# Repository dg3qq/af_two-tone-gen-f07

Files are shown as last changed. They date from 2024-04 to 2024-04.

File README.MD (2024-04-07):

# AF-TWO-TONE-GENERATOR

##### cc-by-sa-nc DG3QQ rodi
##### rev. mar. 2024

# Bastel-Projekt zum 14. Giessener Amateurfunk Tag

+ [expose](F07-project/_expose.md]
+ video interview by Kirk (DO3KI) [14. Gießener Amateurfunktreffen 2024 - Doppeltongenerator Bauprojekt & ARRL Prüfung USA Rufzeichen](https://www.youtube.com/watch?v=AF0V_h3_ksM)

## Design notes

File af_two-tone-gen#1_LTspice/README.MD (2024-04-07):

# Two-Tone-Generator by DG3QQ 

#### copyright: dg3qq (cc-by-sa)

## Circuit Simulations

I used *LTSspice* to tweak parts of the circuit.

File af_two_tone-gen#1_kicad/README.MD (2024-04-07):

# Two-Tone-Generator by DG3QQ 

#### copyright: dg3qq (cc-by-sa)

## PCB in KiCad 

This was an attempt to port PCB development to KiCad. However, due to time constraints it was abandoned.

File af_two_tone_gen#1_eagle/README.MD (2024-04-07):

# Two-Tone-Generator by DG3QQ 

#### copyright: dg3qq (cc-by-sa-nc)

## PCB in EagleCad 

To get around delays, I resorted to a *free* version of EagleCad (6.xx).

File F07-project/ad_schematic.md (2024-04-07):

# Two Tone Generator (c) DG3QQ

##### Rev.: 17.Feb.2024

## Schaltplan - schematic 

SCH

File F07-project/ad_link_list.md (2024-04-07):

# Liks

##### Doc-Rev: 20240114-0023

## software 
+ [DL4YHF's Amateur Radio Software: Audio Spectrum Analyzer ("Spectrum Lab") ](https://www.qsl.net/dl4yhf/spectra1.html)

## websites

+ [DF1RN - NF-Zweitonmessungen am Elecraft KX3 [PDF]](https://www.darc.de/fileadmin/filemounts/distrikte/g/ortsverbaende/01/DF1RN/_16_-_17__NF-Zweitonmessungen_am_Elecraft_KX3_rev._1.1_df1rn_2018_06_25.pdf)
+ [box73 - Bauanleitung zum FA-2-NF-Zweitongenerator](https://www.box73.de/file_dl/bausaetze/BX-086.pdf)
+ [DC4KU - Messungen mit dem HF-Zweitongenerator FA-2-HF von FA [PDF]](https://dc4ku.darc.de/HF-Zweitongenerator_FA-2-HF.pdf)
+ [DC4KU HF-Zweitongenerator für IM3-Messungen an
SSB-Endstufen (PA's) und SSB-Empfängern [PDF]](https://dc4ku.darc.de/HF-Zweitongenerator.pdf)
+ []()
+ [DL2DAP_HF-Messpraxis und Messgeräte für Funkamateure 2021 [PDF]](https://forum.funk-telegramm.de/wcf/attachment/346-dl2dap-hf-messpraxis-und-messger%C3%A4te-f%C3%BCr-funkamateure-2021-pdf/)
+ [dk7ih - A simple 2-tone-generator for testing the linearity of SSB transmitters](https://dk7ih.de/a-simple-2-tone-generator-for-testing-the-linearity-of-ssb-transmitters/)
+ [PreciseRF - Application Note #2; Transmitter Two Tone Test [PDF]](https://preciserf.com/wp-content/uploads/2012/03/Appnote-2-Two-Tone-Tests2.pdf)
+ [Two-tone signal generator](https://www.robkalmeijer.nl/techniek/electronica/radiotechniek/hambladen/hr/1986/02/page25/index.html)

### circuit building block details:
+ [ee-diary: how does Twin-T oscillator work](https://www.ee-diary.com/2021/12/how-does-twin-t-oscillator-work.html#)
+ [Electronics Tutorials - Twin-T Oscillator](https://www.electronics-tutorials.ws/oscillator/twin-t-oscillator.html)
+ [elektroniktutor - sPassive elektrische Filterschaltungen](https://www.elektroniktutor.de/analogtechnik/filter.html#boucherot)

## video link collection

+ [Zweiton-Summensignal aus 700Hz und 1900Hz.]( https://www.youtube.com/watch?v=r9hPcu_xrlM)

+ [w2aew #7: Monitor your Ham Radio transmitter with an oscilloscope (en)](https://www.youtube.com/watch?v=y4Zt_LJX1Tc)
+ [w2aew #8: Two-tone test of SSB transmitter output (en)](https://www.youtube.com/watch?v=3DxBg6h4Fc8)
+ [w2aew #112: Use an Oscilloscope and Signal Generator help tune an HF Antenna, measure complex impedance (en)](https://www.youtube.com/watch?v=eYN7dhdt1Dw)
+ [w2aew #61: Basics of RF Samplers, Sampling-Tees, RF-taps, etc.(en)](https://www.youtube.com/watch?v=0Kk_N_TpDeo)
+ [MikesRadioRepair - Building a simple 2 tone audio generator for testing SSB radios.](https://www.youtube.com/watch?v=bIG2McK9QRQ)

+ [Icom IC-7300 Tips and Tricks - Using Two Tones to Check Linearity](https://www.youtube.com/watch?v=NapPt2sxBVE)
+ []()
+ []()
+ [Kurzwellen SSB Funkgerät nachbauen Teil 1](https://www.youtube.com/watch?v=Qace0_og6LY)
+ [Kurzwellen SSB Funkgerät nachbauen Teil 2](https://www.youtube.com/watch?v=GwzsfukFg70)
+ [Kurzwellen SSB Funkgerät nachbauen Teil 3 es funktioniert](https://www.youtube.com/watch?v=KoNCUYpN4dw)
+ [1 Watt Kurzwellen SSB Funkgerät Schaltplan Teil 4](https://www.youtube.com/watch?v=3-fIp6_WNEs)
+ [https://www.youtube.com/watch?v=M98ClS4ekHA](https://www.youtube.com/watch?v=M98ClS4ekHA)

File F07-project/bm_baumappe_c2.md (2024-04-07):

# Zwei-Ton-Generator - DARC F07 Project (c) DG3QQ

#####  Doc-Rev: 20240224-1440

# Baumappe - Kaptel 2

## Bestückung-Anleitung des PCB

Nachfolgend werden detailliert die Schritte der Bestückung der Platine beschrieben.

Bitte folgen Sie der gegebenen Reihenfolge, denn diese haben sich als sinnvoll und praktikabel erwiesen.

### Bestand-Aufnahme
Bevor es an's Bestücken geht, hat es sich immer als sinnvoll erwiesen, die Vollständigkeit der Materialien zu prüfen.

Bitte identifizieren und prüfen Sie anhand der [Stückliste](ad_bom_sum.md) die Bauteile. Und stellen Sie sicher, dass alle vorhanden sind.

Sortieren sie die dabei die Widerstände. Unter Umständen sind einige der Farbringe nur schwer zu identifizieren; wenn nötig benutzen sie ein Vergrößerungsglas. Am besten benutzen sie ein Multimeter 
um die Werte zu überprüfen.

### Poti's, Schalter und LED zuerst
Die Poti's, Schalter und LED sollen von außen bedienbar bzw. sichtbar sein! 

Deshalb platzieren Sie die Poti's (VR1..VR3), Schalter (S1, S2) und die LED (LED1). Aber noch nicht einlöten! 

Bei der LED ist auf die Polarität zu achten. 

LED polarity advice

Richten Sie diese Bauelemente entsprechen aus und 'heften' (tack solder) Sie diese in Position. 

Wenn alles passt, können Sie die Poti's, Schalter und LED zuverlässig verlöten.

>!Note Leider konnten die im Labormuster verwendeten Sub-Miniatur-Schalter weder in dieser noch vergleichbaren Bauform (zum Termin) beschafft werden. Statt dessen werde funktionsgleiche aber etwas größere mit Litze-Drähten mit dem PCB verbunden.

### Und jetzt fertig bauen

Wer die Funktion der Schaltung verstanden hat, oder ein erfahrener *Nachbauer* ist, mag gerne die folgenden Anweisungen zur weiteren Bestückung der Platine überspringen und *In eigen Regie* weiter bauen. (Nict empfohlen) [->weiter zu Kapitel PCB_Fertig](#PCB_Fertig)

### Schritt für Schritt Anweisungen

Nachdem Sie jetzt VR1.. S1.. und LED1 platziert haben, 
fahren wir mit den den weiteren, Bauteilen fort:

#### Bestückung - Stromversorgung
Die LED1 wurde schon im vorhergehenden Schritt bestückt. Um den Stromversorgung-Teil zu vervollständigen, bestücken sie nun noch:

+ [_] R1 Widerstand 560R 0,25W stehend (grün-blau-braun). 
> !NOTE: Setzen Sie diesen, abweichend vom Bestückungsdruck in umgekehrter Weise ein. Dann kann am langen Ende zu Testzwecken per Laborklemme die Schaltung provisorisch mit *PLUS* der Batterie-Versorgung verbunden werden.

+ [_] C1 Kondensator 100nF (104)

##### Test - Stromversorgung
Jetzt kann ein erster Test dieses Schaltungsteil erfolgen.

Verbinden Sie vorübergehend die Batterie (oder eine vergleichbare Spannungsquelle) mit dem PCB. 

Durch betätigen der Schalter sollte sich folgendes ergeben:

| Schalter | LED | 
| :--- | :--- |
| beide aus | dunkel |
| mindestens einer oder beiden ein | leuchtet |

Wenn die LED in keiner der Stellungen leuchtet, prüfen Sie deren Polarität/Einbau.

#### Bestückung - Erster Oszillator

Bestücken Sie:

+ [_] Widerstand R2 47k liegend (gelb-vio-orange)
+ [_] Widerstand R4 47k stehend (gelb-vio-orange)
+ [_] Kondensator C4 10nF (103)
+ [_] Kondensator C4B 3,3nF (332)
+ [_] Kondensator C3 10nF (103)
+ [_] Kondensator C3B 3,3nF (332)
+ [_] Kondensator C2 22nF (223)
+ [_] Kondensator C5 1µF (105)
+ [_] Kondensator C6 22nF (223)
+ [_] Kondensator C7 22nF (223)
+ [_] Testpunkt TF1 (1x2 pinstrip Sockel (RM2.5))
+ [_] Widerstand R6 4k7 stehend (gelb-vio-rot)
+ [_] Widerstand R7 4k7 stehend (gelb-vio-rot)
+ [_] Transistor T1 NPN-Transistor 2N3904 (o.ä.) 
> Eventuell müssen die Beinchen etwas gebogen werden, damit sie gut in die Bohrungen passen.

#### Bestückung - Zweiter Oszillator

Bestücken Sie:

+ [_] Widerstand R9 33k liegend (orange-orang-orange)
+ [_] Widerstand R10 33k stehend (orange-orang-orange)
+ [_] Widerstand R11 2k2 stehend (rot-rot-braun)
+ [_] Kondensator C9 4,7nF (472)
+ [_] Kondensator C10 4,7nF (472)
+ [_] Kondensator C8 10nF (103)
+ [_] Kondensator C11 1µF (105)
+ [_] Kondensator C12 3,3nF (332)
+ [_] Kondensator C13 3,3nF (332)
+ [_] Testpunkt TF2 (1x2 pinstrip Sockel (RM2.5))
+ [_] Widerstand R12 10k stehend (braun-schwarz-orange)
+ [_] Widerstand R13 10k stehend (braun-schwarz-orange)
+ [_] Transistor T2 NPN-Transistor 2N3904 (o.ä.) (Beinchen biegen)
+ [_] Testpunkt SG (1x2 pinstrip Sockel (RM2.5))

####Bestückung - Ausgang-Puffer-Stufe

Bestücken Sie:

+ [_] Widerstand R20 10k stehend (braun-schwarz-orange)
+ [_] Widerstand R21 10k stehend (braun-schwarz-orange)
+ [_] Widerstand R22 560R stehend (grün-gelb-braun)
+ [_] Widerstand R26 27k stehend (rot-vio-orange)
+ [_] Widerstand R24 5k6 stehend (grün-gelb-rot)
+ [_] Widerstand R25 560R stehend (grün-gelb-braun)
+ [_] Widerstand R23 560R stehend (grün-gelb-braun)
+ [_] Testpunkt  SIG_ (1x3 pinstrip Sockel (RM2.5))
+ [_] Kondensator/Elko C15 10µF radial (Polarität beachten)
+ [_] Kondensator/Elko C16 220µF radial (Polarität beachten)
+ [_] Transistor T3 NPN-Transistor 2N3904 (o.ä.) (Beinchen biegen) 

## PCB Fertig

Sie haben die Platine fertig bestückt. Zum Abschluss nun noch den Batteriehalter verbinden und drei Batterien (Typ-AAA) einlegen.

Nun kann getestet und eingestellt werden.

Am besten prüfen Sie die Funktion mit einem Oszilloskop.

+ [_] Stellen Sie mit VR1 die Frequenz des Oszillator (um T1) auf typisch 700Hz ein.
+ [_] Stellen Sie mit VR2 die Frequenz des Oszillator (um T2) auf typisch 1900Hz ein.
+ [_] Regeln Sie mit VR3 die *Balance* der beiden Signale so, dass sie im Gemisch gleiche Amplitude haben.
Siehe [Benutzer-Anleitung](om_benutzer_anleitung.md) 

### analog oszi schirmbild

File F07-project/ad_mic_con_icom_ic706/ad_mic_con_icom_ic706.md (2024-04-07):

# Zwei-Ton-Generator - DARC F07 Project (c) DG3QQ

#####  Doc-Rev: 20240219-2120

#  Baumappe - Anhang

## Mikrofon-Anschluß f. ICOM IC-706 u.ä.

## 
| PIN  | Signal | Farbe |
| :---: | --- | --- |
| 1 | +8V !!max. 10mA | rot |
| 2 | UP/DOWN | blau  |
| 3 | AUDIO OUT | n/a |
| 4 | PTT | gelb  |
| 5 | MIC GROUND | grau  |
| 6 | MIC | weiss |
| 7 | GROUND/EARTH | grün  |
| 8 | SQUELCH | braun |
  
>note +8V nicht strombegrenzt - Bei Überstrom TRX kaput !
 
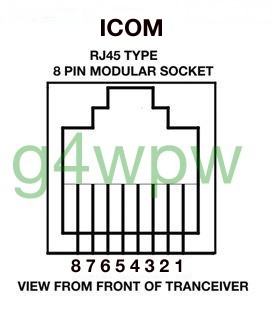
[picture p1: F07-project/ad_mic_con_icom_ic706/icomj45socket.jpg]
icom RJ45

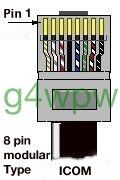
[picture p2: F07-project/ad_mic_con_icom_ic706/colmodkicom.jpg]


### ICOM HM103
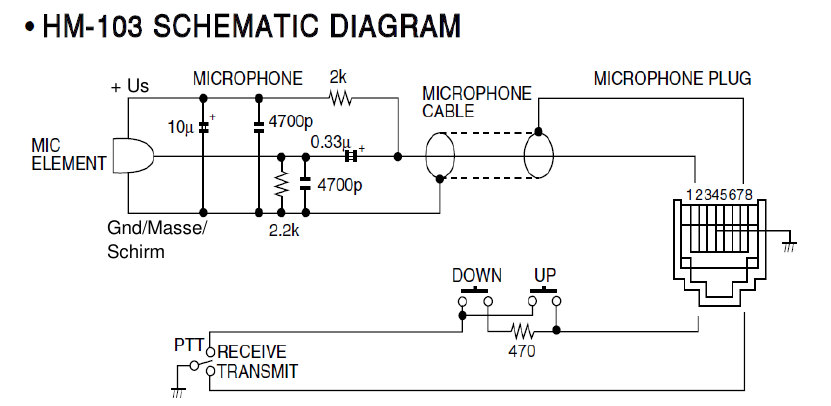
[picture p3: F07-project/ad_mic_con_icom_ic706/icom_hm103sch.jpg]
icom HM103


[g4wpw](https://www.qsl.net/g4wpw/date.html)

![]()

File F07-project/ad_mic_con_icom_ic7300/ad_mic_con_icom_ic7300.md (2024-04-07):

# Zwei-Ton-Generator - DARC F07 Project (c) DG3QQ

#####  Doc-Rev: 20240219-2300

#  Baumappe - Anhang

## Mikrofon-Anschluß f. ICOM IC-7300 

## 
| PIN | Signal | Farbe |
| :---: | --- | --- |
| 1 | MIC | |
| 2 | +8V | |
| 3 | MIC_U/D | |
| 4 | SQL | |
| 5 | PTT | |
| 6 | GND | |
| 7 | MICE | |
| 8 | AF_OUT | |
  
>note +8V 10mA max.
 
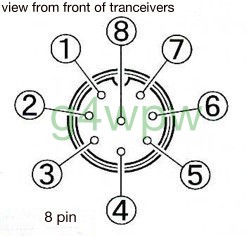
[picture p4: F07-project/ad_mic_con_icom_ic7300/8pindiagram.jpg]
icom 8pin
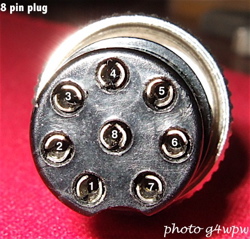
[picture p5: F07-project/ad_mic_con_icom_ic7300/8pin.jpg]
 
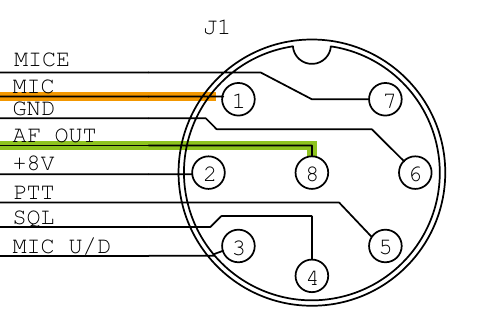
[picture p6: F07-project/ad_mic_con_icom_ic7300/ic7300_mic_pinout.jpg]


### ICOM HM-219
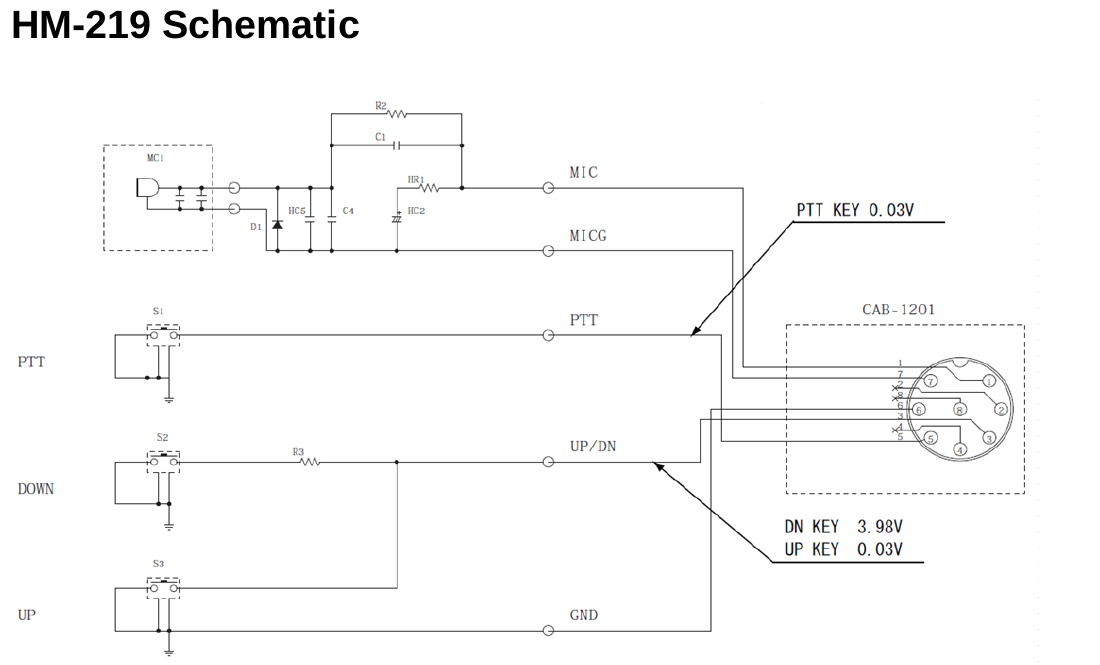
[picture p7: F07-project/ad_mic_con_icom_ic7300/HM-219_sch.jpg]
icom HM-219 schematic


[g4wpw](https://www.qsl.net/g4wpw/date.html)

![]()

## microphon input specs

impedance: 600Ohm
pegel: (von service manual addendum; 4-4 TX POWER ADJUSTMENTS) Level : 30 mVrms

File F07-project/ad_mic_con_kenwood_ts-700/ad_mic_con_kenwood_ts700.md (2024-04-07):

# Zwei-Ton-Generator - DARC F07 Project (c) DG3QQ

#####  Doc-Rev: 20240219-2120

#  Baumappe - Anhang

## Mikrofon-Anschluß f. KENWOOD TS-700G u.ä.

## 
| PIN  | Signal |
| :---: | --- |
| 1 | MIC |
| 2 | PTT |
| 3 | PTT GND |
| 4 | MIC GND |
    
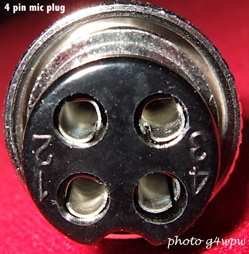
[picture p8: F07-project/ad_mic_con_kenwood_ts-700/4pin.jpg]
4pin
    

### kenwood MC-10
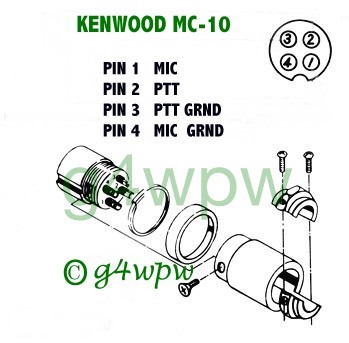
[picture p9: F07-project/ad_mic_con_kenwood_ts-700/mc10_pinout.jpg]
kenwood


[g4wpw](https://www.qsl.net/g4wpw/date.html)

![]()

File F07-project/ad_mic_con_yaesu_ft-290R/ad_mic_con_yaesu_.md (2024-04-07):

# Zwei-Ton-Generator - DARC F07 Project (c) DG3QQ

#####  Doc-Rev: 20240219-2120

#  Baumappe - Anhang

## Mikrofon-Anschluß f. YAESU FT-290R u.ä.

## 
| PIN  | Signal |
| :---: | --- |
| 1 | MIC Schirm/Masse |
| 2 | MIC |
| 3 | PTT |
| 4 | + 12VOLT ( + 5 VOLTS FT730-FT290R ) |
| 5 | SPEAKER |
| 6 | UP |
| 7 | DOWN |
    
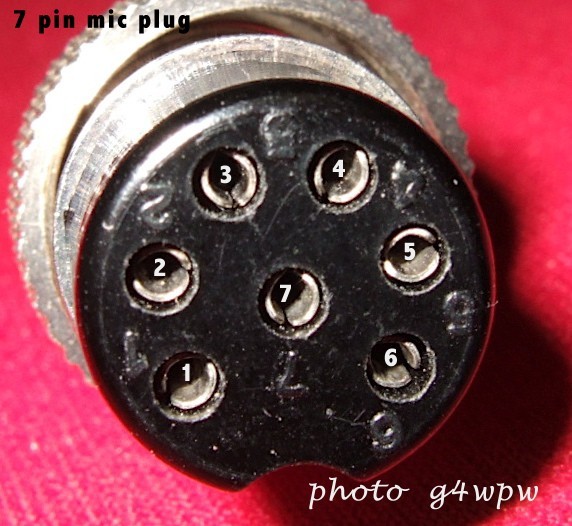
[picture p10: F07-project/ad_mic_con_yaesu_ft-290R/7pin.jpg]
7pin
    

### yaesu YM-47
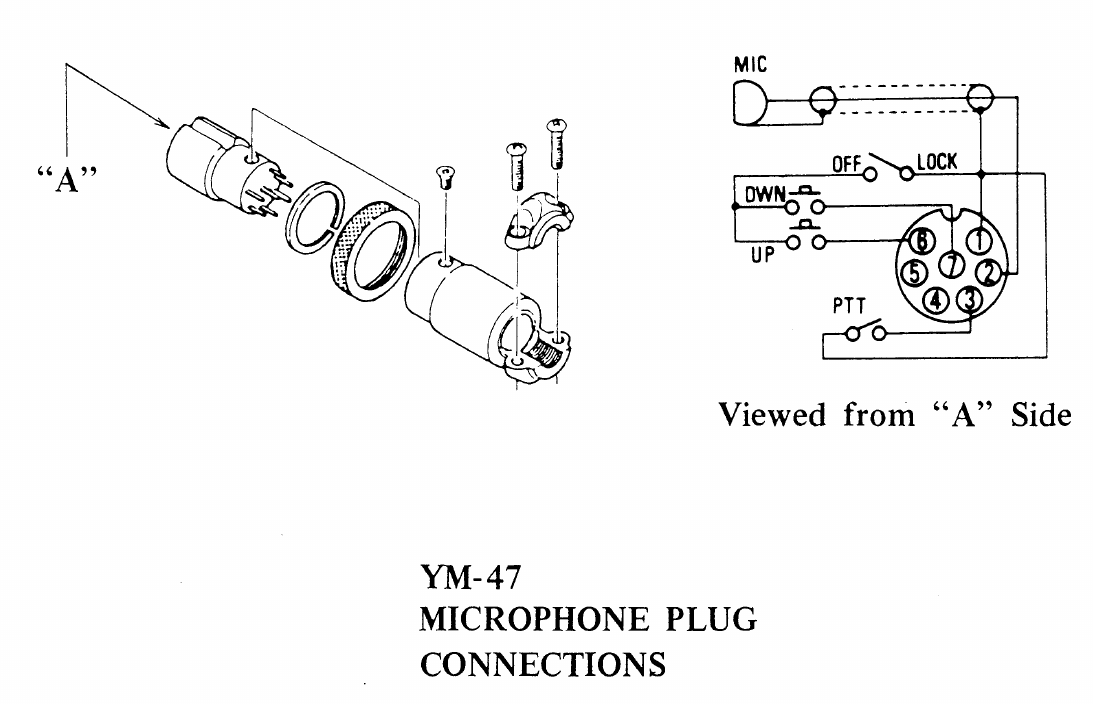
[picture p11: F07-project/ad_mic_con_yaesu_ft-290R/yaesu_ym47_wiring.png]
yaesu YM-47


### yaesu YM-49
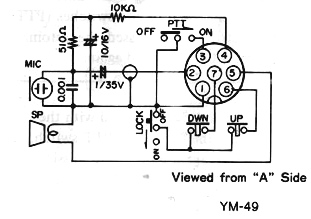
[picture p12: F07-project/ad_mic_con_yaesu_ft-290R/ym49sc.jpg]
yaesu YM-49


[g4wpw](https://www.qsl.net/g4wpw/date.html)

![]()

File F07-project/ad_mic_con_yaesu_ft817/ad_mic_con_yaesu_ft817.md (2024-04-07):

# Zwei-Ton-Generator - DARC F07 Project (c) DG3QQ

#####  Doc-Rev: 20240219-2120

#  Baumappe - Anhang

## Mikrofon-Anschluß f. YAESU FT-817 u.ä.

## 
| PIN | Signal | Farbe |
| :---: | --- | --- |
| 1 | FAST SCAN.  | rot (red) |
| 2 | GROUND. | braun (brown) |
| 3 | PTT. | gelb (yellow) |
| 4 | MIC. | weiss (white) |
| 5 | MIC GROUND. | schwarz (black) |
| 6 | + 5 VOLTS.  | grün (green) |
| 7 | UP. | blau (blue) |
| 8 | DOWN. | schwarz (black) | 

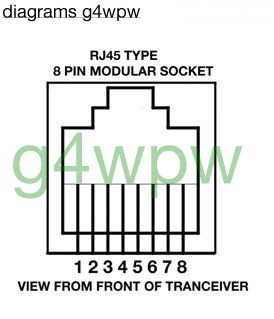
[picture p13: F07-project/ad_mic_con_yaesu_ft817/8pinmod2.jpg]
RJ45
    

### yaesu HM-31A8J
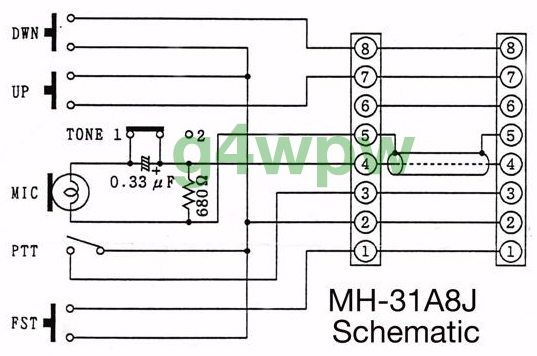
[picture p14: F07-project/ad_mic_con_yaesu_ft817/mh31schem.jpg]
MH31 schematic


### yaesu MH-31 Specifications
+ Microphone Element: Dynamic
+ Audio Tone Response: Tone 1 Full range. Tone 2 -14dB ±3 dB at 100 Hz
+ Sensitivity: -78 dB ±3dB at 1 kHz
+ Microphone Impedance: 190 Ohms ±30% at 1 kHz (Tone 1)
+ Dimensions: 2.5 x 4.5 x 1.25 inches
+ Weight: 7 ounces (183 g). 

[g4wpw](https://www.qsl.net/g4wpw/date.html)

## yaesu 6-pin mini-DIN (FT-817)
| PIN  | Signal |
| :---: | --- |
| 1 | Data In (1Vpp; 10kOhm)|
| 2 | GROUND |
| 3 | PTT |
| 4 | Data Out 9600bps |
| 5 | Data Out 1200bps (300mVpp; 10kOm)|
| 6 | SQL |

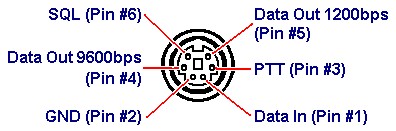
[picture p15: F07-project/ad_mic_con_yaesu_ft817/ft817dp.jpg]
DATA port
6-pin mini-DIN (FT-817) DATA port

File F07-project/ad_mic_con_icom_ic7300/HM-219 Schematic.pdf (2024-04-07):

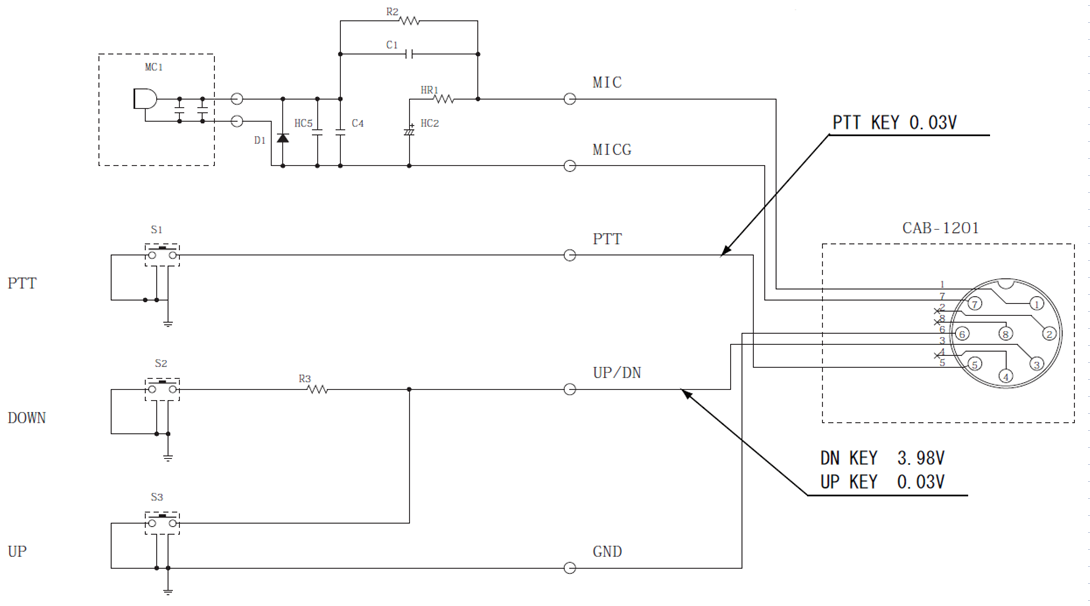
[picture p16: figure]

1

# Knowledge Base |

©2018 Icom America Inc. The Icom logo is a registered trademark of Icom Inc.

# HM-219 Schematic

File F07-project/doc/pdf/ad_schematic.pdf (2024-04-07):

Two Tone Generator (c) DG3QQ

Rev.: 17.Feb.2024
Schaltplan - schematic

1

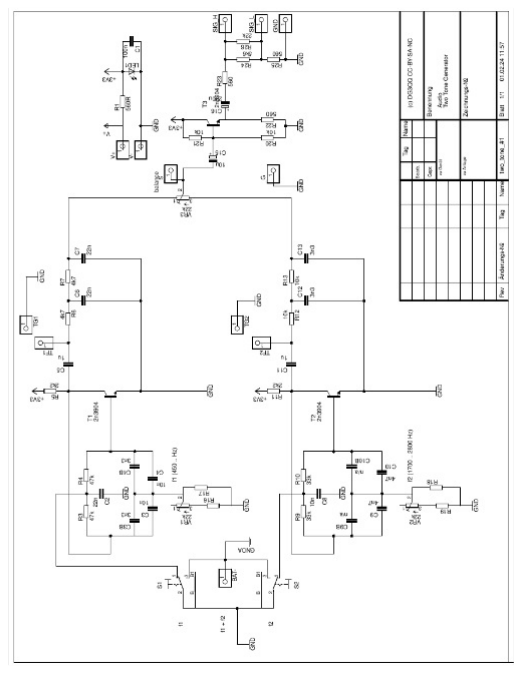
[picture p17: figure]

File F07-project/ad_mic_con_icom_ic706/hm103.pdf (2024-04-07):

# HM 103 Handmikrofon

# funktioniert auch am IC-7000

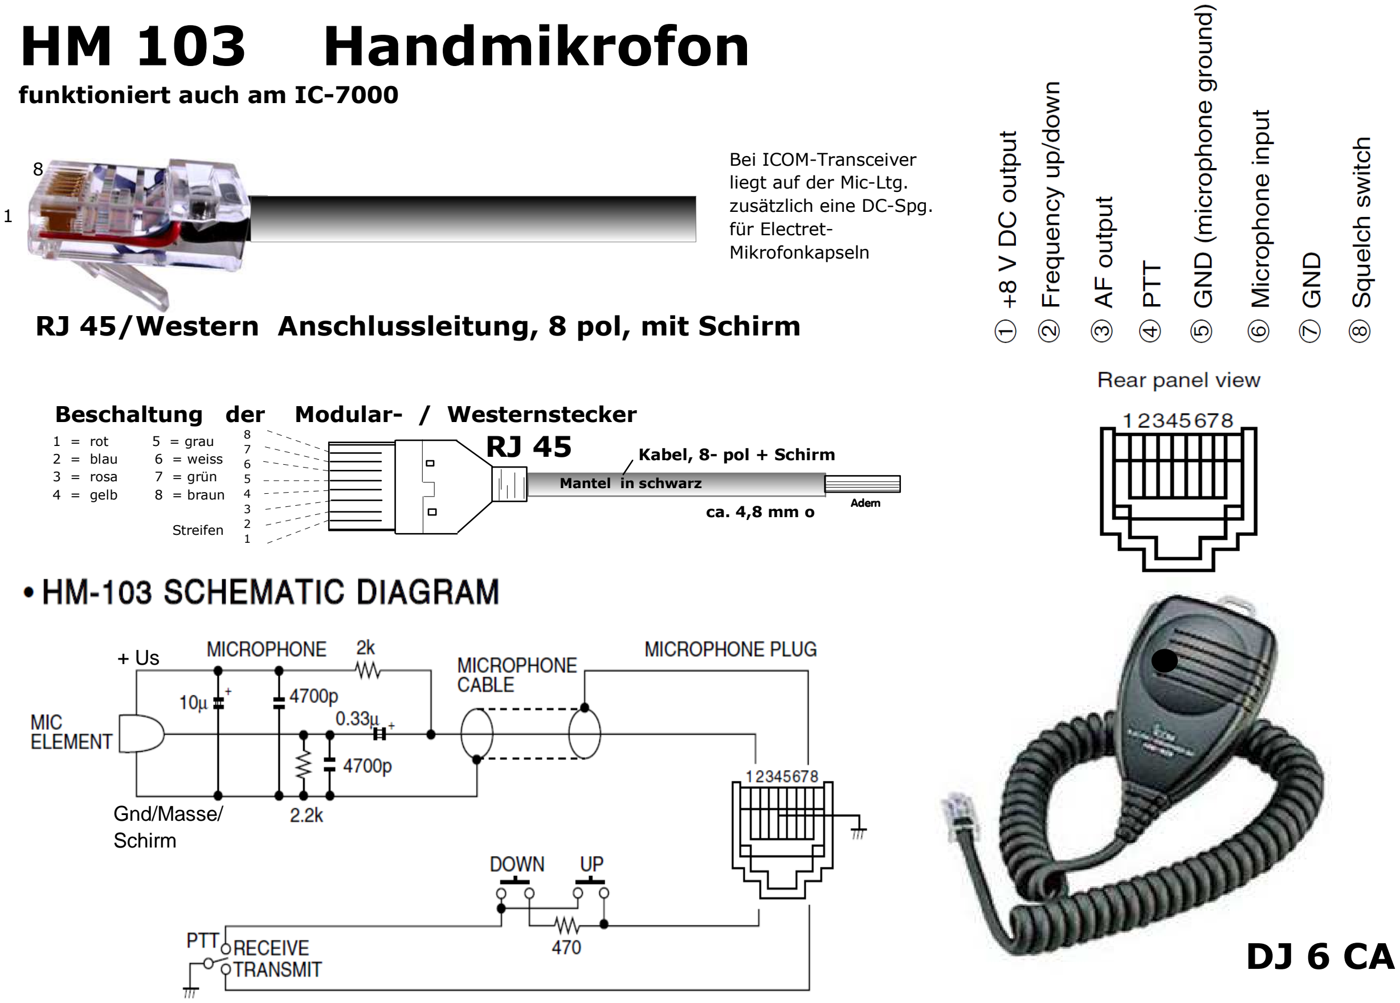
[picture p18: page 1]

# RJ 45/Western Anschlussleitung, 8 pol, mit Schirm

8

1

## Beschaltung der Modular- / Westernstecker

### Kabel, 8- pol + Schirm

Adern

Mantel in schwarz

ca. 4,8 mm o

RJ 45 ¹ = rot | 5 = grau 2 = blau | 6 = weiss
3 = rosa | 7 = grün
4 = gelb | 8 = braun

Streifen

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
# DJ 6 CA

+ Us

# Gnd/Masse/ Schirm

### Bei ICOM-Transceiver

liegt auf der Mic-Ltg.
zusätzlich eine DC-Spg.

### für Electret-Mikrofonkapseln

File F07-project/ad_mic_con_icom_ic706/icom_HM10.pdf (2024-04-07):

## IC-HM10

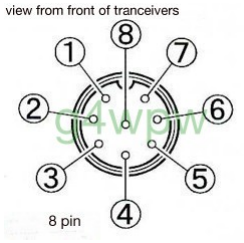
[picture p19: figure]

PIN 1 | MIC.
PIN 2 | +9 volt.
PIN 3 | UP/DOWN.
PIN 4 | SQUELCH.
PIN 5 | PTT.
PIN 6 | PTT GROUND.
PIN 7 | MIC GROUND.
PIN 8 | N/C.
HM10 | https://www.qsl.net/g4wpw/hm10.html
1 von 1 | 15.02.24, 21:47

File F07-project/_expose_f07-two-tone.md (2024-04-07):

# *TWO TONE TEST OSZILLATOR*  - ein Selbstbau-Projekt
##### Exposee; Rev.: 27.Dec.2023

##### ToDo: 
[ ] Rechtschreibprüfung

Noch eines; warum nicht? - Es stand die Frage im Raum, ob der OV-F07 für 2024 ein "Bastel-Projekt" realisiert.

## Anforderungen zur Entwicklung:
 + soll in eine *"Pfefferminz Dose"* passen. Oder zumindest nicht viel größer sein.
 + Batterie betrieben (3x AAA)
 + keine SMD sondern nur bedrahtete Bauteile (THT); eben was zum anfassen ;) !
 + keine µController

## Schaltung-Beschreibung
Der Hauptteil des Geräts besteht aus zwei Twin-T-Oszillatoren (Transistorschaltung). 
Deren Frequenz kann jeweils mittels eines Spindel-Trimers eingestellt werden. 
Die beiden Signale werden danach über einen weiteren Spindel-Trimer, zur *Balance*-Einstellung, gemischt. 
Eine nachfolgende Verstärkerstufe dient der Entkopplung und Impedanzanpassung.

Für den Aufbau der Schaltung auf der Leiterplatte kommen bedrahtete Bauteile zum Einsatz.

Die Anfertigung von Anschlusskabel(n) für das zu testende Geräte, ist wegen der Vielfalt, dem Besitzer/Erbauer überlassen. 
Jedoch werden in der Baumappe Beispiele hierfür gegeben. 

## Bauteile:
 + 3 Transistoren, 1 3mm ø LED
 + 3 Spindeltrimmpoti
 + 2 Miniatur-Kippschalter
 + 22 Widerstände (1/4W)
 + 17 Kondensatoren
 + 2 Al-Elko

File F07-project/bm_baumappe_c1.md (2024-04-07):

# Zwei-Ton-Generator - DARC F07 Project (c) DG3QQ

#####  Doc-Rev: 20240205-1257

#  Baumappe - Kapitel 1

## Schaltungsbeschreibung

### Überblick / Blockdiagramm
block diagram

Wie im obigen Blockdiagramm dargestellt, besteht der beschriebene Zweiton-Generator aus zwei Oszillatoren mit jeweils einem nachgeschalteten Tiefpass. Die Frequenzen sind mit RV1 bzw. RV2 in gewissem Maße einstellbar. 

Danach werden die beiden NF-Sinus-Signale in einer passiven Mischstufe (RV3) einander überlagert.

Abschließend folgt eine Impedanzwandler-/Puffer-Stufe (T3). In deren Auskopplung ist auch ein Abschwächer vorhanden.

Nachfolgend werden die einzelnen Stufen näher beschrieben. 

#### Oszillator-Schaltung

Als Oszillator-Schaltung kommt hier die "Twin-T"-Konfiguration mit einem NPN-Transistor als Verstärker zum Einsatz.

Andere Oszillator-Schaltungen, wie z.B. Wien-Brücke, Phasen-Netzwerk o. andere, erfordern mehr Aufwand an Bauteilen/Schaltung-Komplexität. Oder sind nicht geeignet mit einfachen Mitteln, innerhalb eine Oktave nach oben oder unten verstimmt/eingestellt zu werden. 

Twin_T_oscillator

[wikipedia: Twin-T_oscillator](https://en.wikipedia.org/wiki/RC_oscillator#Twin-T_oscillator)

Der Oszillator besteht aus einem Verstärker und einem Rückkopplung-Netzwerk. 

In diesem speziellen Fall ist es eine Parallelschaltung von RCR-Tiefpass und CRC-Hochpass in T-Anordnung

Mit :
R1 = R; R2 = 1/2 * R und

C1 = C; C2 = 2 * C

Gilt für die Bestimmung der Frequenz:

"fc={\frac {1}{2\pi RC}}"

Durch Variation von Widerstand (R2) ist es, in begrenztem Maße möglich, die Resonanzfrequenz zu ziehen; Plus/Minus eine halbe Oktave geht.

Viel tiefer in die Funktionsweise der "Twin-T"-Oszillatorschaltung möchte ich hier aber nicht weiter eingehen. -> [elektronik-labor. de - Eintransistor-Sinusoszillator (www.elektronik-labor.de/Notizen/SinusOsz.html)](https://www.elektronik-labor.de/Notizen/SinusOsz.html)

Halbleiter-Schaltungstechnik, Tietze, Ulrich; Schenk, Christoph; Springer-Verlag  

#### Tiefpass-Filter

Eine "Twin-T"-Oszillatorschaltung ist gegenüber einem *Wien*-Oszillator mit einem höheren Klirrfaktor behaftet. Dem wird hier mit passiven (RC)-Tiefpass-Filtern in ausreichender weise entgegen gewirkt.

#### NF-Überlagerung / Mischer u. Balance Einstellung

Die Überschrift für diese Stufe erscheint komplizierter als es ist.

Die NF-Signale der vorausgehenden Stufen werden an die gegenüberliegenden Enden  eines Potentiometer eingespeist. An dessen Abgriff bildet sich dann das Überlagerung-Signal.

Je nach Eingang-Amplitude und Stellung des Abgriff wird hier (mit VR3) die *Balance*
der beiden Tonsignale im Verhältnis 1:1 eingestellt.

#### Puffer-/Impedanzwandler-Stufe

Eigentlich könnte man hier aufhören und das Signal an dieser Stelle ausleiten. 

Es ist jedoch sinnvoll hier eine  niederohmige Impedanz-/Puffer-Stufe (T3) vorzusehen. 

#### Spannungsversorgung

Da das Gerät für den ungebundene Einsatz konzipiert wurde, sind zur Versorgung Primär-Zellen (3xAAA) vorgesehen.

Die Spannung-Stabilisierung erfolgt durch eine "Shunt"-Schaltung. Eine LED (blau; ø3mm) wird als Referenz eingesetzt. Zusätzlich dient diese LED auch als Betrieb-Anzeige.

#### Funktionskontrolle

Bezüglich der Funktion-Kontrolle muss hier besonders auf die Verwendung der Kontakte der beiden Schalter hingewiesen werden.

Zum einen verbinden diese jeweils den Negativ-Batterie-Anschluss mit der Schaltung (ODER Verknüpfung).

Zum anderen kann der Kondensator im Tiefpasszweig am "Twin-T"-Oszillator gegen Masse gebrückt werden (aus). 

Auf diese weise wird möglich mit nur zwei einpoligen Umschaltern (SPST) folgendes Funktion-Verhalten zu erreichen.
 
| S1 | S2  | Stromversorgung | Ausgang (Frequenz) |
| --- | --- | :--- | --- |
| aus | aus | aus; Batterie nicht verbunden | 0 |
| ein  | ein  | ein; Batterie verbunden | f1 + F2 | 
| ein  | aus | ein; anderer Oszillator (f2) gesperrt | f1 | 
| aus | ein  | ein; anderer Oszillator (f1) gesperrt | f2 |

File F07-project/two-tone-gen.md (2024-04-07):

# Project Audio Two Tone Generator (C) DG3QQ  

##### Doc-Rev: 20240114-0023
#### copyright: dg3qq (cc-by-sa)

## Dokumente in deutscher Sprache
- [Expose f07-two-tone-expose.md](f07-two-tone-expose.md)
- [Baumappe bm_baumappe.md](bm_baumappe.md)
- [Benutzer Anleitung om_benutzer_anleitung.md](om_benutzer_anleitung.md)
- [DUT Adapter Beispiele ad_dut_harness_de.md](ad_dut_harness_de.md)

## Documents in english
- [Builder's manual bm_build_manual.md](bm_build_manual.md)
- [Operation manual om_operator_manual.m](om_operator_manual.md)

## Apendix / Anhang
- [Bill Of Materials - Stückliste ad_bom.md](ad_bom.md)
- [Schematic - Schaltplan ad_schematic.md](ad_schematic.md)

## links other
Wenn man im Internet sucht, wird man viele Artikel zu diesem Thema finden.

+ [wikipedia:Zweiton.jpg; Cqdx; CC BY-SA 3.0 Deed](https://de.wikipedia.org/wiki/Datei:Zweiton.jpg)
+ [Cqdx; CC BY-SA 3.0 Deed](https://de.wikipedia.org/wiki/Datei:Zweiton.jpg)

+ [wikipedia - Zweitonanregung](https://de.wikipedia.org/wiki/Zweitonanregung) 
+ [wikipedia - Two-tone testing](https://en.wikipedia.org/wiki/Two-tone_testing)
+ [dc4ku - NF-Doppeltongenerator für IM3-Messungen an SSB-Sender](https://dc4ku.darc.de/NF-Doppelton-Generator.pdf)
+ [dc4ku - Intermodulationsmessung_an_HF-Sendern und HF-Endstufen (PA)](https://dc4ku.darc.de/Intermodulationsmessung_an_HF-Sendern.pdf)

+ [dl6gl - Klirrarmer Zweitongenerator; dl6gl](https://dl6gl.de/klirrarmer-zweitongenerator.html)
+ [aarl - Test Procedures Manual](https://www.arrl.org/files/file/Technology/Procedure%20Manual%202011%20with%20page%20breaks.pdf) Two-Tone Audio
Generator pp. 140
+ [cwtd - Analyze This! ... Two-Tone Test Oscillator](http://www.cwtd.org/Sep17.html)
+ [vk6ysf - SINGLE SIDE BAND TWO TONE TEST](https://vk6ysf.com/ssb_2tone_test.htm)
+ [dk7ih - A simple 2-tone-generator for testing the linearity of SSB transmitters](https://dk7ih.de/a-simple-2-tone-generator-for-testing-the-linearity-of-ssb-transmitters/)
+ [oz1bxm - Designing and Building a Two-Tone Generator](http://oz1bxm.blogspot.com/2016/04/designing-and-building-two-tone.html)
+ [ELECRAFT - 2T-gen 2-Tone TESTOSCILLATOR](https://ftp.elecraft.com/Mini%20Modules/Manuals%20Downloads/2T-Gen_Manual_Rev_B.pdf)
+ [pc2c - Two tone LF generator](https://www.pc2c.nl/two_tone_gen.php)
+ [kx4om - Two-Tone Generator](https://www.qsl.net/kx4om/Projects/Two-ToneGen/Two-Tone_Generator.html)
+ [DK7IH - Das QRP-Baubuch – Kapitel 4 (Teil 5) 4.11.1 Das Zweitonverfahren](https://dk7ih.de/das-qrp-baubuch-kapitel-4-5/)
+ []()
+ []()
+ []()

+ [VU2ESE - Two Tone HF-Generator](https://www.vu2ese.com/index.php/2020/06/19/two-tone-generator/)

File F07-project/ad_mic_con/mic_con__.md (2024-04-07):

# Zwei-Ton-Generator - DARC F07 Project (c) DG3QQ

#####  Doc-Rev: 20240219-2120

#  Baumappe - Anhang

## Mikrofon-Anschluß - allgemeine Hinweise

+ Eingangsschaltung des DUT
+ Bei DUT (Elektret-Mikrofon) Koppelkondensator in Mikrofon-Leitung (4,7µF)
+ Pegel:
    + Dyn-Mikrofon = ca. 2mV (ohne ext. Vorverstärker)
    + Elektret = 20 mV bis 100mV
    
## 
| PIN  | Signal |
| :---: | --- |
| 1 |  |
| 2 |  |
| 3 |  |
| 4 |  |
| 5 |  |
| 6 |  |
| 7 |  |
    
7pin    

### ?? 
??

[g4wpw](https://www.qsl.net/g4wpw/date.html)

![]()

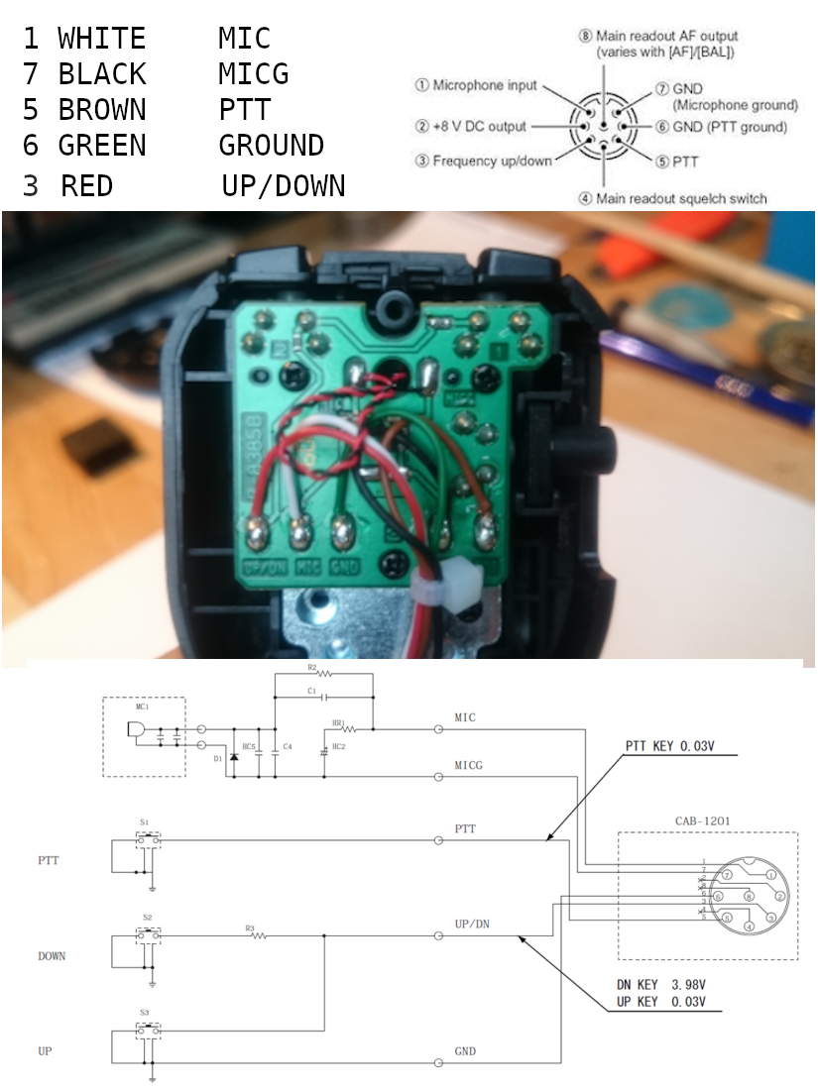
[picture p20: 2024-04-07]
F07-project/ad_mic_con_icom_ic7300/HM-219-schematic.png

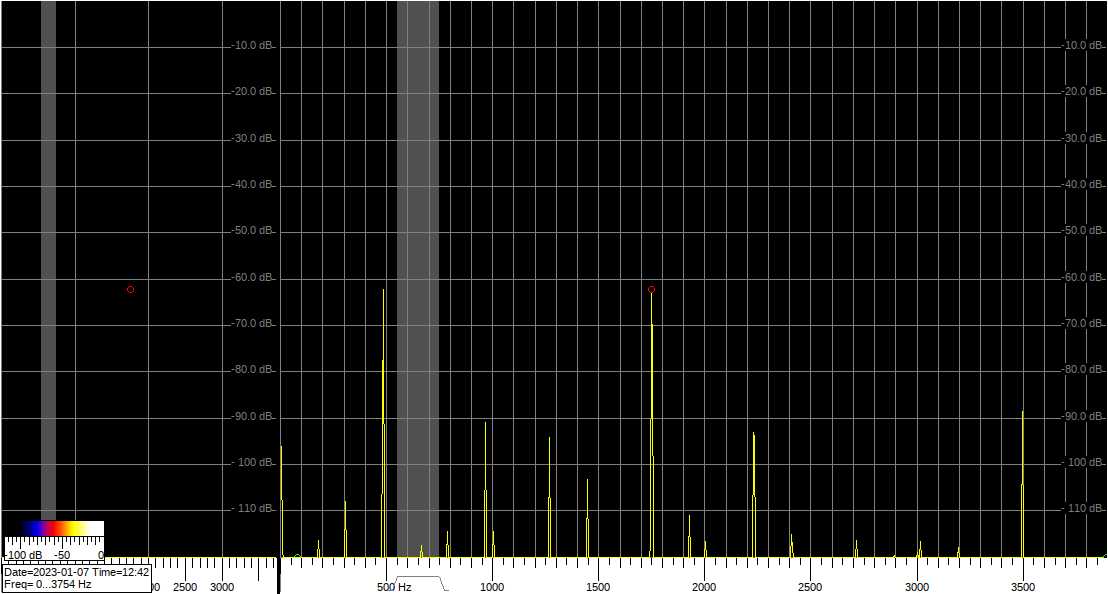
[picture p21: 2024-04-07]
pictures/w_psu_usb.jpg

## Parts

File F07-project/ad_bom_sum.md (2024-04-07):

# Two Tone Generator - DARC F07 Project (c) DG3QQ

#####  Doc-Rev: 20240224-1350

## Stückliste - Bill Of Materials

### Widerstände - Resitors 
| check | Qty  | type/value | id | comment |
| :---  | ---: | :--- | :--- | :--- |
| [___] | 4 | 560 0,25W | R1, R22, R23, R25 | . |
| [___] | 2 | 2k2 0,25W | R5, R11| . |
| [___] | 2 | 4k7 0,25W | R6, R7| . |
| [___] | 1 | 5k6 0,25W | R24 | . |
| [___] | 4 | 10k 0,25W | R12, R13, R20, R21| . |
| [___] | 1 | 22k 0,25W | R26 | . |
| [___] | 2 | 33k 0,25W | R9 R10| . |
| [___] | 2 | 47k 0,25W | R3, R4| . |
| [___] | 2 | 0R | R16, R19 | Brücke mit langen Enden (Harnadelform) |
| | 2 | na | R17, R18 | . |

### Kondensatoren - Capacitors
| check | Qty  | type/value | id | comment |
| :---  | ---: | :--- | :--- | :--- |
| [___] | 4 | 3n3 (332) | C3B, C4B, C12, C13 | . |
| [___] | 2 | 4n7 (472) | C9, C10| . |
| [___] | 3 | 10n (103) | C3, C4, C8 | . |
| [___] | 3 | 22n (223) | C2, C6, C7 | . |
| [___] | 1 | 100n (104) | C1 | . |
| [___] | 2 | 1µ0 (105) | C5, C11 | . |

### Elektrolyt-Kondensator - Elko
| check | Qty  | type/value | id | comment |
| :---  | ---: | :--- | :--- | :--- |
| [___] | 1 | 10µF 16V radial | C15 | . |
| [___] | 1 | 220µF 25V radial | C16 | . | 

### Transistoren - Transistors 
| check | Qty | type/value | id | comment |
| :---  | ---: | :--- | :--- | :--- |
| [___] | 3 | NPN SI-Transistor 2N3904 | T1, T2, T3 | o.ä. |

### Diodes - Dioden (LED) 
| check | Qty | type/value | id | comment |
| :---  | ---: | :--- | :--- | :--- |
| [___] | 1 | LED blue ø3mm | LED1 | EVERSTAR R3040HBDE034 |

### Potentiometer 
| check | Qty | type/value | id | comment |
| :---  | ---: | :--- | :--- | :--- |
| [___] | 3 | 22k/20turn trimpot.| VR1, VR2, VR3  | . |

### ... div.
| check | Qty | type/value  | id | comment |
| :---  | ---: | :--- | :--- | :--- |
| [___] | 2 | miniature switch SPST | S1, S2 | MTS-102-A1 |
| [___] | 3 | Buchsenleiste 1x2 pin | TF1, TF2, _S | |
| [___] | 1 | Buchsenleiste 1x3 pin | TFO | . |
| [___] | 1 | PCB | x1 | AllPCB |
| [___] | 1 | Batteriehalter 3xAAA | x2 | . |

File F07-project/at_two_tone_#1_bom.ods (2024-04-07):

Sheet: Tabelle1
id | device | value | name A | name B | name C | pollin# | reichelt# | preis/stk (EUR) | stk | ve
T1, T2, T3 | Transistor | 2N3904 | CDIL Bipolar, Kleinleistungstransistor, 2N3904, NPN |  | TO-92, | 131521 |  | 0,05 | 3 | 1 | 0,15 | 4,5
LED1 | LED | ø 3mm, blau | QUADRIOS LED, 3 mm, Lichtfarbe: Blau, Gehäusefarbe: Diffus, 1300 mcd, 460 nm, 2,54 mm |  |  | 121862 |  | 0,05 | 0 | 1 | 0 | 0
 |  |  | QUADRIOS LED, 3 mm, Lichtfarbe: Blau, Gehäusefarbe: Klar, 2500 mcd, 460 nm, 2,54 mm |  |  | 121875 |  | 0,06 | 0 | 1 | 0
 |  |  | QUADRIOS LED, 3 mm, Lichtfarbe: Blau, Gehäusefarbe: Diffus-Blau, 1300 mcd, 460 nm, 2,54 mm |  |  | 121851 |  | 0,05 | 0 | 1 | 0
 |  |  | EVERSTAR LEDs ESL-R3040HBDE034, blau, 3 mm, 10 Stück |  |  | 121317 |  | 1,03 | 1 | 10 | 0,103 | 3,09 | 7,59
C16 | elko | 220µF | TEAPO Alu-Elko, KSH227M035S1G5H12K, 220uF, 35V, |  | RM 5, radial, 105°C, 10x12mm | 211011 |  | 0,09 | 0 | 1 | 0
 |  |  | JAMICON Elektrolytkondensator, 220µF, 25, bis +105°C, ±20% |  | Maße(ØxH): 8x11,5 mm | 210875 |  | 0,17 | 0 | 1 | 0
 |  |  | TEAPO Alu-Elko, KSH227M016S1A5E11K, 220uF, 16V, |  | RM 2,5, radial, 105°C, 6,3x11mm | 211001 |  | 0,05 | 1 | 1 | 0,05 | 1,5
C15 | elko | 10µF | TEAPO Miniatur-Alu-Elko, KSS106M025S1A5B07K, 10uF, 25V, RM 2,5, radial, 105°C, 4x7mm |  |  | 210984 |  | 0,04 | 1 | 1 | 0,04 | 1,2
 |  |  | TEAPO Alu-Elko, KSH106M035S1A5C11K, 10uF, 35V, RM 2, radial, 105°C, 5x11mm |  |  | 211008 |  | 0,04 | 0 | 1 | 0
 |  |  | Elko, radial, 10 µF, 63 V, 105 °C, RM 2,5 |  |  | 210397 |  | 0,04 | 0 | 1 | 0
C5, C11 | Kondensator | 1 µF | KEMET Folienkondensator, 1 µF, 63 V, 10 % |  | RM 5, | 200918 |  | 0,3 | 2 | 1 | 0,6 | 0
C1 | Kondensator | 100 nF | KEMET Folienkondensator, 100nF, 63V 100 nF - ± 10 % - 63 V - 5 RM - radial. |  |  | 200913 |  | 0,07 | 0 | 1 | 0 | 0
 |  |  | RICHWELL Keramik-Kondensator, 100 nF, 50 V, RM 5, 20 % |  |  | 201108 |  | 0,06 | 0 | 1 | 0
 |  |  | Keramik-Vielschicht-Kondensator, 100 nF, 50 V, RM 5, 10 % ,Keramikart: X7R |  |  | 201065 |  | 0,11 | 1 | 1 | 0,11
 |  |  | KEMET Keramik-Vielschicht-Kondensator, 100 nF, 50 V, RM 2,5, 10 % |  |  | 201048 |  | 0,09 | 0 | 1 | 0
 |  |  | EPCOS Folienkondensator B32529, 100 nF 0,1 µF, 10 %, 63 V-, RM 5 mm, Maße (LxBxH): 7,5x2,5x6,5 mm. |  |  | 201195 |  | 0,08 | 0 | 1 | 0
C2, C6, C7 | Kondensator | 22 nF | RICHWELL Keramik-Kondensator, 22 nF, 100 V, RM 5, 20 % Keramikart: Z5U |  |  | 201106 |  | 0,06 | 0 | 1 | 0
 |  |  | Folienkondensator, 22nF, 100V 22 nF - ± 10 % - 100 V - 5 RM – radial. |  |  | 200910 |  | 0,11 | 0 | 1 | 0 | 0
 |  |  | EPCOS Folienkondensator B32520, 22 nF 0,022 µF, 10 %, 400 V-, RM 7,5 mm, radial. |  |  | 200314 |  | 0,13 | 0 | 1 | 0
 |  |  | TANCAP TECHNOLOGY Keramikkondensator, 22nF, 50V Keramik-Vielschicht-Kondensator, RM 2,5, 100 V, 10 % Keramikart: X7R |  |  | 201045 |  | 0,1 | 0 | 1 | 0
 |  |  | VISHAY Folien-Kondensator MKP1840, 22 nF |  |  | 200780 |  | 0,06 | 3 | 1 | 0,18
C3, C4, C8 | Kondensator | 10 nF | Folienkondensator, 10 nF 10 nF, 10 %, 100 V-, MKT, RM 5 mm. |  |  | 200602 |  | 0,05 | 0 | 1 | 0 | 0
 |  |  | RICHWELL Keramikkondensator, 10 nF, 100 V, 10 % Keramik-Kondensator, RM 2,5, 100 V, 10 % Keramikart: Y5V |  |  | 201085 |  | 0,07 | 0 | 1 | 0
 |  |  | TANCAP TECHNOLOGY Keramik-Vielschicht-Kondensator, 10 nF, 50 V, RM 2,5, 10 % Keramikart: X7R |  |  | 201044 |  | 0,16 | 3 | 1 | 0,48
 |  |  | TANCAP TECHNOLOGY Keramik-Vielschicht-Kondensator, 10 nF, 50 V, RM 5, 10 % Keramik-Vielschicht-Kondensator, RM 5, 50 V, 10 % Keramikart: X7R |  |  | 201061 |  | 0,13 | 0 | 1 | 0
C9, C10 | Kondensator | 4,7 nF | RICHWELL Keramik-Kondensator, 4,7 nF, 100 V, RM 5, 20 % |  |  | 201104 |  | 0,09 | 0 | 1 | 0
 |  |  | TANCAP TECHNOLOGY Keramik-Vielschicht-Kondensator, 4,7 nF, 100 V, RM 5, 10 % Keramikart: X7R |  |  | 201060 |  | 0,16 | 0 | 1 | 0
 |  |  | KEMET Folienkondensator, 4,7nF, 100V 4,7 nF - ± 10 % - 100 V - 5 RM – radial. |  |  | 200907 |  | 0,08 | 0 | 1 | 0 | 9,6
 |  |  | KEMET Keramik-Vielschicht-Kondensator, 4,7 nF, 100 V, RM 2,5, 10 % Keramik-Vielschicht-Kondensator, RM 2,5, 100 V, 10 % Keramikart: X7R |  |  | 201043 |  | 0,07 | 0 | 1 | 0
 |  |  | Keramikkondensator, 4700 pF 4,7 nF, 10 %, 100 V-, radial, RM 2,54. |  |  | 200336 |  | 0,05 | 2 | 1 | 0,1
C3B, C4B, C12, C13 | Kondensator | 3,3 nF | Keramikkondensator, 3300 pF , 3,3 nF, 20 %, 63 V-, RM 5 mm, radial. |  |  | 200330 |  | 0,02 | 4 | 1 | 0,08 | 2,4
 |  |  | Keramikkondensator, 10 Stück 3,3 nF, 63 V-, 20 %, RM 2,54 mm, radial. 10 Stück. |  |  | 200144 |  | 0,5 | 0 | 10 | 0
 |  |  | Folien-Kondensator, 3,3 nF, 100 V MKT - 3,3 nF - 100 V - RM 5 – radial |  |  | 200747 |  | 0,05 | 0 | 1 | 0
 |  |  |  |  |  |  |  |  |  |  |  |  | 14,7
R9, R10 | Widerstand | 33k | Kohleschicht-Widerstand, 33 kΩ, 100 Stück 33 kΩ - 0,25 W - 5 % - 100 Stück |  |  | 220071 |  | 1,5 | 2 | 100 | 0,03 | 1,5
 |  |  | Widerstand, Kohleschicht, 33k Ohm, 1/4W 5%, 50 Stück |  |  | 221598 |  | 1,39 | 0 | 50 | 0
R12, R13, R20, R21 | Widerstand | 10k | Kohleschicht-Widerstand, 0,25 W, 10K, 5 %, 100 Stück |  |  | 220068 |  | 1,5 | 4 | 100 | 0,06 | 3
 |  |  | Widerstand, Kohleschicht, 10K Ohm, 1/4W 5%, 50 Stück |  |  | 221596 |  | 1,39 | 0 | 50 | 0
R1, R22, R23, R25 | Widerstand | 560R | Kohleschicht-Widerstand, 560 Ω, 100 Stück |  |  | 221450 |  | 1,5 | 4 | 100 | 0,06 | 3
R24 | Widerstand | 5k6 | Kohleschicht-Widerstand, 5,6 kΩ, 100 Stück |  |  | 221454 |  | 1,5 | 1 | 100 | 0,015 | 1,5
R26 | Widerstand | 22k | Kohleschicht-Widerstand 22 kΩ - 0,25 W - 5 % - 100 Stück |  |  | 220070 |  | 1,5 | 1 | 100 | 0,015 | 1,5
 |  |  | Widerstand, Kohleschicht, 22k Ohm, 1/4W 5%, 50 Stück |  |  | 221597 |  | 1,39 | 0 | 50 | 0
R3, R4 | Widerstand | 47k | Kohleschicht-Widerstand, 47 kΩ, 100 Stück |  |  | 220072 |  | 1,5 | 2 | 100 | 0,03 | 1,5
 |  |  | Widerstand, Kohleschicht, 47 Ohm, 1/4W 5%, 50 Stück |  |  | 221586 |  | 1,39 | 0 | 50 | 0
R5, R11 | Widerstand | 2k2 | Kohleschicht-Widerstand, 2,2 kΩ, 100 Stück |  |  | 220064 |  | 1,5 | 2 | 100 | 0,03 | 1,5
 |  |  | Widerstand, Kohleschicht, 2.2K Ohm, 1/4W 5%, 50 Stück |  |  | 221594 |  | 1,39 | 0 | 50 | 0
R6, R7 | Widerstand | 4k7 | Kohleschicht-Widerstand, 4,7 kΩ, 100 Stück |  |  | 220066 |  | 1,5 | 2 | 100 | 0,03 | 1,5
 |  |  | Widerstand, Kohleschicht, 4.7K Ohm, 1/4W 5%, 50 Stück |  |  | 221595 |  | 1,39 | 0 | 50 | 0
RV1, RV2, RV3 | Spindeltrimmer | 22k | Spindeltrimmer 414S6, 22K |  |  | 240480 |  | 0,2 | 3 | 1 | 0,6 | 18 |  | https://www.pollin.de/p/spindeltrimmer-414s6-22k-240480
 |  |  |  |  |  |  |  |  |  |  |  |  | 33
S1, S2 | Schalter | SPDT | Kippschalter MTS-102-A1 , 1Pol EIN-EIN, 3 A/250 V Lötanschluss Knebellänge: 11 mm Ø 6,4 mm |  |  | 420179 |  | 0,89 | 0 | 1 | 0 | 0
 |  |  | MS 244 MIYAMA KIPPSCHALTER SUBMINI. MIYAMA 1XU |  |  | ELW #00056823 |  | 1,72 | 2 | 1 | 3,44 | 103,2 |  | https://elw-elektronik.com/epages/d0dee231-ab0f-4fe3-b9b2-78e23c1b0b52.sf/de_DE/?ObjectID=19843201
 |  |  | CONNFLY ELECTRONIC Buchsenleiste, vergoldet, 1x 20-polig |  |  | 451498 |  | 0,36 | 1 | 1 | 0,36 | 10,8
 |  |  | CONNFLY ELECTRONIC Buchsenleiste, vergoldet, 1x 40-polig |  |  | 451500 |  | 0,86 | 0 | 1 | 0 | 0
 |  |  | CONNFLY ELECTRONIC Buchsenleiste, vergoldet, 1x 16-polig |  |  | 451497 |  | 0,32 | 0 | 1 | 0 | 0
 |  |  | ECON CONNECT Buchsenleiste, vergoldet, 1x 2-polig |  |  | 451552 |  | 0,07 | 3 | 1 | 0,21 | 6,3
 |  |  | CONNFLY ELECTRONIC Buchsenleiste, vergoldet, 1x 3-poli |  |  | 452476 |  | 0,16 | 1 | 1 | 0,16 | 4,8
X3 | Beutel | ZipLock | QUADRIOS, 1903EC111, Zip-Beutel Dissipativ 10 St 75 x 125mm |  |  | 110204 |  | 2,3 | 1 | 10 | 0,23 | 6,9
 |  |  |  |  |  |  |  |  |  |  | 7,163
 |  |  |  |  |  |  |  |  |  |  |  |  | 132
 |  |  |  |  |  |  |  |  | 30 |  | 214,89 | 187,29 | 187,29
X2 | Batteriehalter | 3 x AAA | HALTER 3XAAA Battery holder for 3x Micro AAA, closed |  |  |  | HALTER 3XAAA | 2,2 | 1 | 1 | 2,2
 |  |  |  |  |  |  |  |  | 30 |  | 66
X1 | Leiterplatte | af_two_tone_#1
 | Ware | post /a package | total
Popllin Bestellung Total | 187,29 € | 6,50 € | 193,79 €
Reichelt Bestellung Total | 66,00 € | 6,50 € | 72,50 €
ALLPCB zero_run | n/a | n/a | 46,59 €
ALLPCF production_run | n/a | n/a | 73,12 €
Total |  |  | 386,00 €
Total/Bausatz |  |  | 12,87 €

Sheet: eagle_bom_two_tone_#1
Qty | Value | Device | Package | Parts | Description
12 |  | PINHD-1X1 | 1X01 | BAT-, OUT_G, OUT_GND, OUT_S, OUT_SIG_H, OUT_SIG_L, TP_F1, TP_F2, TP_GND, TP_GND1, V+, V- | PIN HEADER
1 | 100n | C-EU025_050-025X075 | C025_050-025X075 | C1 | CAPACITOR, European symbol
2 | n/a | C-EU025_050-025X075 | C025_050-025X075 | C10B, C14 | CAPACITOR, European symbol
1 | 10u | CPOL-EUE2.5-5 | E2,5-5 | C15 | POLARIZED CAPACITOR, European symbol
1 | 220u | CPOL-EUE5-10.5 | E5-10,5 | C16 | POLARIZED CAPACITOR, European symbol
3 | 22n | C-EU025_050-025X075 | C025_050-025X075 | C2, C6, C7 | CAPACITOR, European symbol
3 | 10n | C-EU025_050-025X075 | C025_050-025X075 | C3, C4, C8 | CAPACITOR, European symbol
4 | 3n3 | C-EU025_050-025X075 | C025_050-025X075 | C3B, C4B, C12, C13 | CAPACITOR, European symbol
2 | 1u | C-EU025_050-025X075 | C025_050-025X075 | C5, C11 | CAPACITOR, European symbol
2 | 4n7 | C-EU025_050-025X075 | C025_050-025X075 | C9, C10 | CAPACITOR, European symbol
1 |  | LED3MM | LED3MM | LED1 | LED
5 |  | R-EU_0207/2V | 0207/2V | R1, R16, R17, R18, R19 | RESISTOR, European symbol
1 | 33k | R-EU_0207/2V | 0207/2V | R10 | RESISTOR, European symbol
4 | 10k | R-EU_0207/2V | 0207/2V | R12, R13, R20, R21 | RESISTOR, European symbol
3 | 22k | R-TRIMM_414S6 | SPINDLE_414S6 | R2, R8, R14
3 | 560 | R-EU_0207/2V | 0207/2V | R22, R23, R25 | RESISTOR, European symbol
1 | 5k6 | R-EU_0207/2V | 0207/2V | R24 | RESISTOR, European symbol
1 | 22k | R-EU_0207/2V | 0207/2V | R26 | RESISTOR, European symbol
1 | 47k | R-EU_0207/10 | 0207/10 | R3 | RESISTOR, European symbol
1 | 47k | R-EU_0207/2V | 0207/2V | R4 | RESISTOR, European symbol
2 | 2k2 | R-EU_0207/2V | 0207/2V | R5, R11 | RESISTOR, European symbol
2 | 4k7 | R-EU_0207/2V | 0207/2V | R6, R7 | RESISTOR, European symbol
1 | 33k | R-EU_0207/10 | 0207/10 | R9 | RESISTOR, European symbol
2 |  | 9070-1W | 9070-1W | S1, S2 | TOGGLE SWITCH
3 | 2n3904 | 2N3904-NPN-TO92-EBC | TO92-EBC | T1, T2, T3 | NPN Transistror

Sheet: allpcb_zero_run
ALLPCB | PCB fab. Zero_run
 |  |  | pcs
Bestellung Stückzahl |  |  | 5
 | USD ($) | EUR (€)
Product cost:$ 1.00 | 1,00 | 0,91 €
Shipping cost:$ 28.00 | 28,00 | 25,48 €
Flotation price:$ 0.00 | 0,00 | 0,00 €
Service Charge:$ 1.09 | 1,00 | 0,91 €
Total amount:$ 30.09 | 30,09 | 27,30 €
PayPal | 29,09 | 26,47 €
DHLKosten (Zoll, USt 19% u.Bearbeitung) |  | 20,12 € | PayPal Online bezahl
Order Total | === | 46,59 €

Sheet: allpcb_production_run
ALLPCB | PCB fab. Production_run
 |  |  | pcs
Bestellung Stückzahl |  |  | 30
 | USD ($) | EUR (€)
Product cost: | 28,00 | 27,30 €
Shipping cost: | 30,00 | 27,30 €
Flotation price: | 0,00 | 0,00 €
Service Charge: | 0,00 | 0,00 €
Total amount: | 60,00 | 52,78 €
PayPal |  | 53,00 €
DHLKosten (Zoll, USt 19%) |  | 20,12 €
Order Total | === | 73,12 €

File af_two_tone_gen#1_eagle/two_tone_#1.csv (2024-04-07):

Qty | Value | Device | Package | Parts | Description
2 |  | 9070-1W | 9070-1W | S1, S2 | TOGGLE SWITCH
1 |  | LED3MM | LED3MM | LED1 | LED
12 |  | PINHD-1X1 | 1X01 | BAT-, OUT_G, OUT_GND, OUT_S, OUT_SIG_H, OUT_SIG_L, TP_F1, TP_F2, TP_GND, TP_GND1, V+, V- | PIN HEADER
5 |  | R-EU_0207/2V | 0207/2V | R1, R16, R17, R18, R19 | RESISTOR, European symbol
1 | 100n | C-EU025_050-025X075 | C025_050-025X075 | C1 | CAPACITOR, European symbol
4 | 10k | R-EU_0207/2V | 0207/2V | R12, R13, R20, R21 | RESISTOR, European symbol
3 | 10n | C-EU025_050-025X075 | C025_050-025X075 | C3, C4, C8 | CAPACITOR, European symbol
1 | 10u | CPOL-EUE2.5-5 | E2,5-5 | C15 | POLARIZED CAPACITOR, European symbol
2 | 1u | C-EU025_050-025X075 | C025_050-025X075 | C5, C11 | CAPACITOR, European symbol
1 | 220u | CPOL-EUE5-10.5 | E5-10,5 | C16 | POLARIZED CAPACITOR, European symbol
1 | 22k | R-EU_0207/2V | 0207/2V | R26 | RESISTOR, European symbol
3 | 22k | R-TRIMM_414S6 | SPINDLE_414S6 | R2, R8, R14
3 | 22n | C-EU025_050-025X075 | C025_050-025X075 | C2, C6, C7 | CAPACITOR, European symbol
2 | 2k2 | R-EU_0207/2V | 0207/2V | R5, R11 | RESISTOR, European symbol
3 | 2n3904 | 2N3904-NPN-TO92-EBC | TO92-EBC | T1, T2, T3 | NPN Transistror
1 | 33k | R-EU_0207/10 | 0207/10 | R9 | RESISTOR, European symbol
1 | 33k | R-EU_0207/2V | 0207/2V | R10 | RESISTOR, European symbol
4 | 3n3 | C-EU025_050-025X075 | C025_050-025X075 | C3B, C4B, C12, C13 | CAPACITOR, European symbol
1 | 47k | R-EU_0207/10 | 0207/10 | R3 | RESISTOR, European symbol
1 | 47k | R-EU_0207/2V | 0207/2V | R4 | RESISTOR, European symbol
2 | 4k7 | R-EU_0207/2V | 0207/2V | R6, R7 | RESISTOR, European symbol
2 | 4n7 | C-EU025_050-025X075 | C025_050-025X075 | C9, C10 | CAPACITOR, European symbol
3 | 560 | R-EU_0207/2V | 0207/2V | R22, R23, R25 | RESISTOR, European symbol
1 | 5k6 | R-EU_0207/2V | 0207/2V | R24 | RESISTOR, European symbol
2 | n/a | C-EU025_050-025X075 | C025_050-025X075 | C10B, C14 | CAPACITOR, European symbol

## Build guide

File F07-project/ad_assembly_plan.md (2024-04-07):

# Zwei-Ton-Generator (c) DG3QQ

##### Rev.: 27.Dec.2023

## Bestückungsplan - assembly plan 

PCB assembly plan

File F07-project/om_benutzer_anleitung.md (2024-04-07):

# Zwei-Ton-Generator (c) DG3QQ

#####  Doc-Rev: 20240219-2300

## Benutzeranleitung

Welche Frequenzen für den AF-Zwei-Ton-Generator?. Wichtig ist, [VK5JST] daß diese nicht in einem *harmonischen* Verhältnis zueinander stehen.

+ F1 nicht ganzzahlig Vielfaches oder Teil von F2
+ Oberwellen/-Töne von F1 nicht ganzzahlig Vielfaches oder Teil von F2 oder deren Oberwellen/-Töne
+ Abstand von ca. 300Hz von den Eckfrequenzen des Übertragungsbandes

Das *AARL Test Procedures Manual*, als auch viele andere Veröffentlichungen, benutzen für die zwei Töne die Frequenzen von 700Hz und 1900Hz.

### frequencies used
| source | f1 | f2 | comment |
| :--- | :---: |  :---: |  :--- |
| AARL Test Procedures Manual | 700 | 1900 | |
| VK5JST | 600 - 700 | 1800 - 2000 |  i.e. about 300Hz from either end of the audio pass band |
| vk6ysf | 700 | 1900 | |
| vk4znc | 800 | 1800 | |
| dk7ih  | 800 | 1350 | |
| dk7ih  | 850 | 2200 | |
| dc4ku  | 1350 | 1900 | |
| dc4ku  | 1075 | 1500 | |
| dl6gl  |  700 | 1900 | |
| gw3spa |  700 | 1900 | |
| ttg2 hendriks | 700 | 1900 | |
| ttg1 preciserf | 700 | 1900 | |
| TwoTone_v2s qrpkits |  750 | 1900 | |
| f6cer  | 1000 | 1300 | |
| f2dc |  720 | 1890 | |
| pc2c | 1000 | 1300 | |
| motorola note | 1000 | 1800 | |

## Einstellung
### Frequenz(en)
Stellen Sie die beiden Oszillatoren auf die gewünschten Betrieb-Frequenzen (Typ 700Hz und 1900Hz) ein.

### Amplituden (Balance)

Die Amplitude der beiden Sinus-Signale muss gleich sein.

#### Einstellung mit dem Oszilloskop

Eingang CH1 mit dem Ausgang des Generator verbinden.

Um ein stehendes Bild zu erreichen verbinde man einen der Testpunkte (TF1 o. TF2) mit dem zweiten Kanal des Oszilloskop oder dessen extern Trigger-Eingang und stell das so ein.

##### TEKTRONIX 645 
analog scope width=20%
##### UNI-T DSO 
DSO width=20% 

#### Einstellung mit dem PC/Laptop und FFT-Analizer

Ich schlage hier DL4YHF's Spectrum Lab (Audio Signal Analyser) vor.

>Note: Beachten Sie, daß der Mikrofon-Eingang hier für die Verwendung von Elektret-Mikrofonen ausgelegt ist. Prüfen sie ob die Phantom-Speisung separat geführt ist und/oder ein DC-Block-Kondensator dann erforderlich wird.

Verbinde den Ausgang des Generator mit dem PC-Sound-Interface.

Stelle die Parameter der verwendeten Software ein.

In dem dargestellte FFT-Diagramm sollten nun die beiden Grund-Töne von Oszillator F1 (mittels VR1) und F2 (mittels VR2) auf die gewünschte Arbeitsfrequenz eingestellt werden. Danach wird über VR3 die Magnitude der beiden Signale auf Gleichheit eingestellt.

## Messaufbau 
Ich muss Sie hier mehr oder weniger alleine lassen. 

Es war nicht und wird es auch nicht sein, mit dem hier beschriebenen AF-Zweiton-Generator die Aspekte der RF-Messtechnik zu vermitteln.
Zum einen gibt es einige gute Artikel hierzu; zum anderen sei unbedingt auf die technische Dokumentation des Gerätes (TRX) verwiesen.

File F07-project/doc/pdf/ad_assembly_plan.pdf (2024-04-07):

## Zwei-Ton-Generator (c) DG3QQ

Rev.: 27.Dec.2023
Bestückungsplan - assembly plan

1

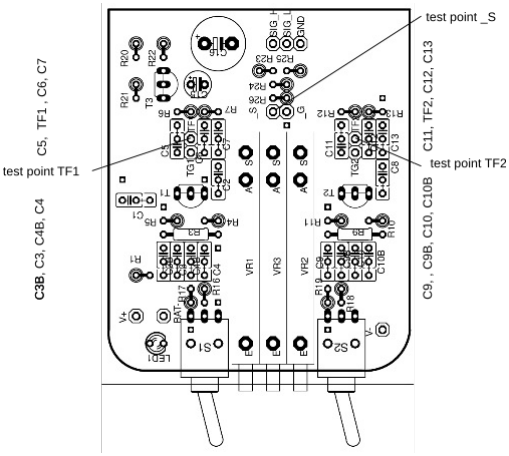
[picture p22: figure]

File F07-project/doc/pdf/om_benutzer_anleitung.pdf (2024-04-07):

# Zwei-Ton-Generator (c) DG3QQ

Doc-Rev: 20240219-2300

## Benutzeranleitung

Welche Frequenzen für den AF-Zwei-Ton-Generator?. Wichtig ist, [VK5JST] daß diese nicht in einem harmonischen Verhältnis zueinander stehen. F1 nicht ganzzahlig Vielfaches oder Teil von F2

Oberwellen/-Töne von F1 nicht ganzzahlig Vielfaches oder Teil von F2 oder deren Oberwellen/-Töne
Abstand von ca. 300Hz von den Eckfrequenzen des Übertragungsbandes
Das AARL Test Procedures Manual, als auch viele andere Veröffentlichungen, benutzen für die zwei Töne die Frequenzen von 700Hz und 1900Hz. frequencies used
source | f1 | f2 | comment
AARL Test Procedures Manual | 700 | 1900
VK5JST | 600 - 700 1800 - 2000 i.e. about 300Hz from either end of the
| | | audio pass band
vk6ysf | 700 | 1900
vk4znc | 800 | 1800
dk7ih | 800 | 1350
dk7ih | 850 | 2200
dc4ku | 1350 | 1900
dc4ku | 1075 | 1500
dl6gl | 700 | 1900
gw3spa | 700 | 1900
ttg2 hendriks | 700 | 1900
ttg1 preciserf | 700 | 1900
TwoTone_v2s qrpkits | 750 | 1900
f6cer | 1000 | 1300
f2dc | 720 | 1890
pc2c | 1000 | 1300
motorola note | 1000 | 1800

## Einstellung

### Frequenz(en)

Stellen Sie die beiden Oszillatoren auf die gewünschten Betrieb-Frequenzen (Typ 700Hz und

### 1900Hz) ein. Amplituden (Balance)

Die Amplitude der beiden Sinus-Signale muss gleich sein. Einstellung mit dem Oszilloskop

1

Eingang CH1 mit dem Ausgang des Generator verbinden. Um ein stehendes Bild zu erreichen verbinde man einen der Testpunkte (TF1 o. TF2) mit dem

zweiten Kanal des Oszilloskop oder dessen extern Trigger-Eingang und stell das so ein. TEKTRONIX 645

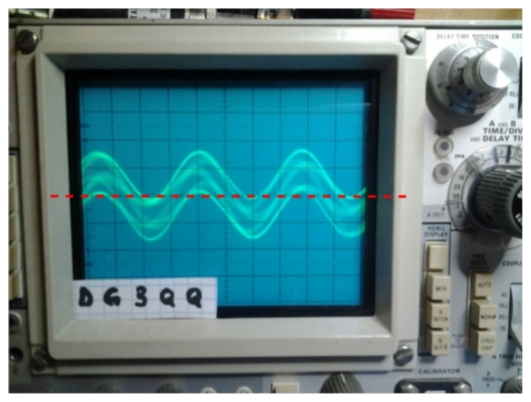
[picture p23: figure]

UNI-T DSO

2

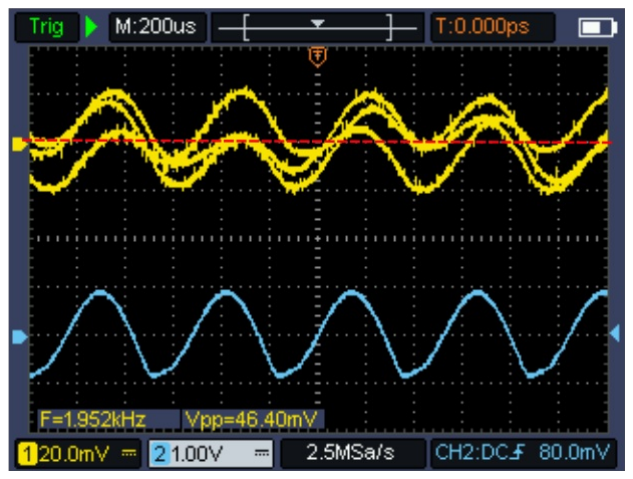
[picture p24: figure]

Einstellung mit dem PC/Laptop und FFT-Analizer
Ich schlage hier DL4YHF's Spectrum Lab (Audio Signal Analyser) vor. Note: Beachten Sie, daß der Mikrofon-Eingang hier für die Verwendung von Elektret-Mikrofonen

ausgelegt ist. Prüfen sie ob die Phantom-Speisung separat geführt ist und/oder ein DC-Block- Kondensator dann erforderlich wird. Verbinde den Ausgang des Generator mit dem PC-Sound-Interface. Stelle die Parameter der verwendeten Software ein. In dem dargestellte FFT-Diagramm sollten nun die beiden Grund-Töne von Oszillator F1 (mittels

VR1) und F2 (mittels VR2) auf die gewünschte Arbeitsfrequenz eingestellt werden. Danach wird über VR3 die Magnitude der beiden Signale auf Gleichheit eingestellt. Messaufbau

Ich muss Sie hier mehr oder weniger alleine lassen. Es war nicht und wird es auch nicht sein, mit dem hier beschriebenen AF-Zweiton-Generator die

Aspekte der RF-Messtechnik zu vermitteln. Zum einen gibt es einige gute Artikel hierzu; zum
anderen sei unbedingt auf die technische Dokumentation des Gerätes (TRX) verwiesen. | 3

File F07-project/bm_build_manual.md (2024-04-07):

# Two Tone Generator - DARC F07 Project (c) DG3QQ
# Build Manual

As time of writing, there is no native translation to this document.
Pleas use google.translate

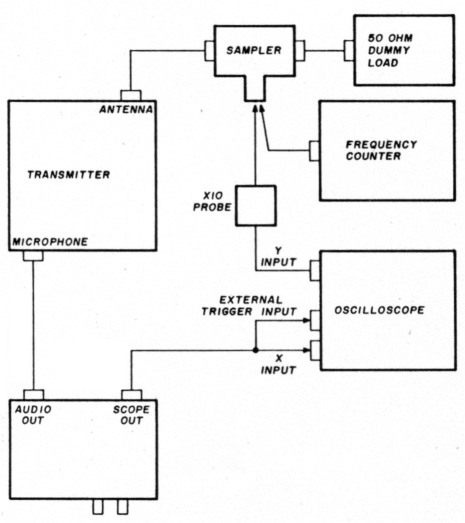
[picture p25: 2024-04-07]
F07-project/asset/setup_YB9ATA_fig1.jpg

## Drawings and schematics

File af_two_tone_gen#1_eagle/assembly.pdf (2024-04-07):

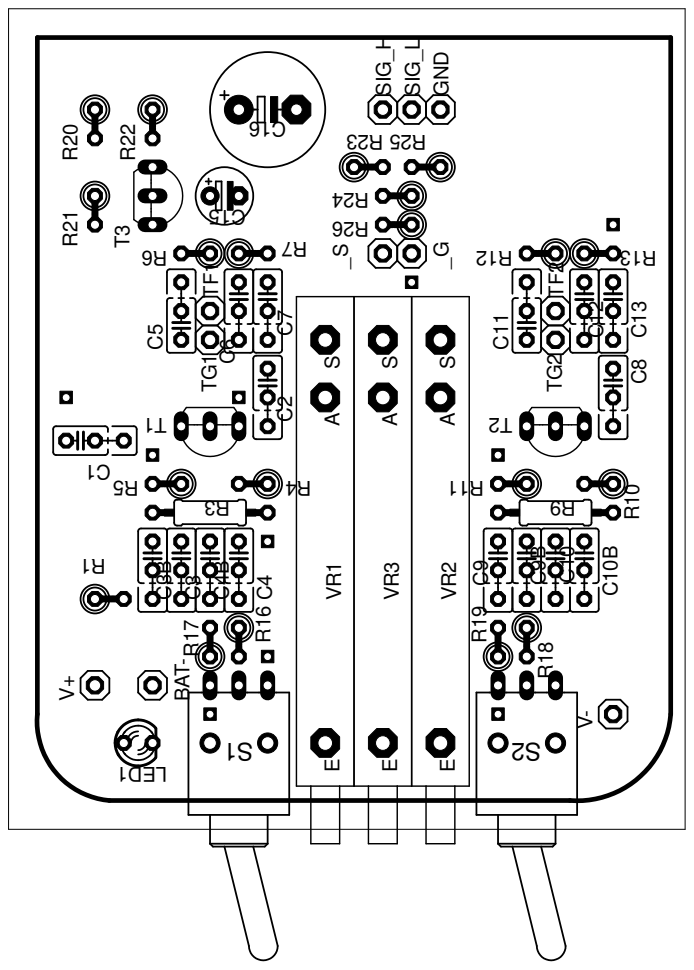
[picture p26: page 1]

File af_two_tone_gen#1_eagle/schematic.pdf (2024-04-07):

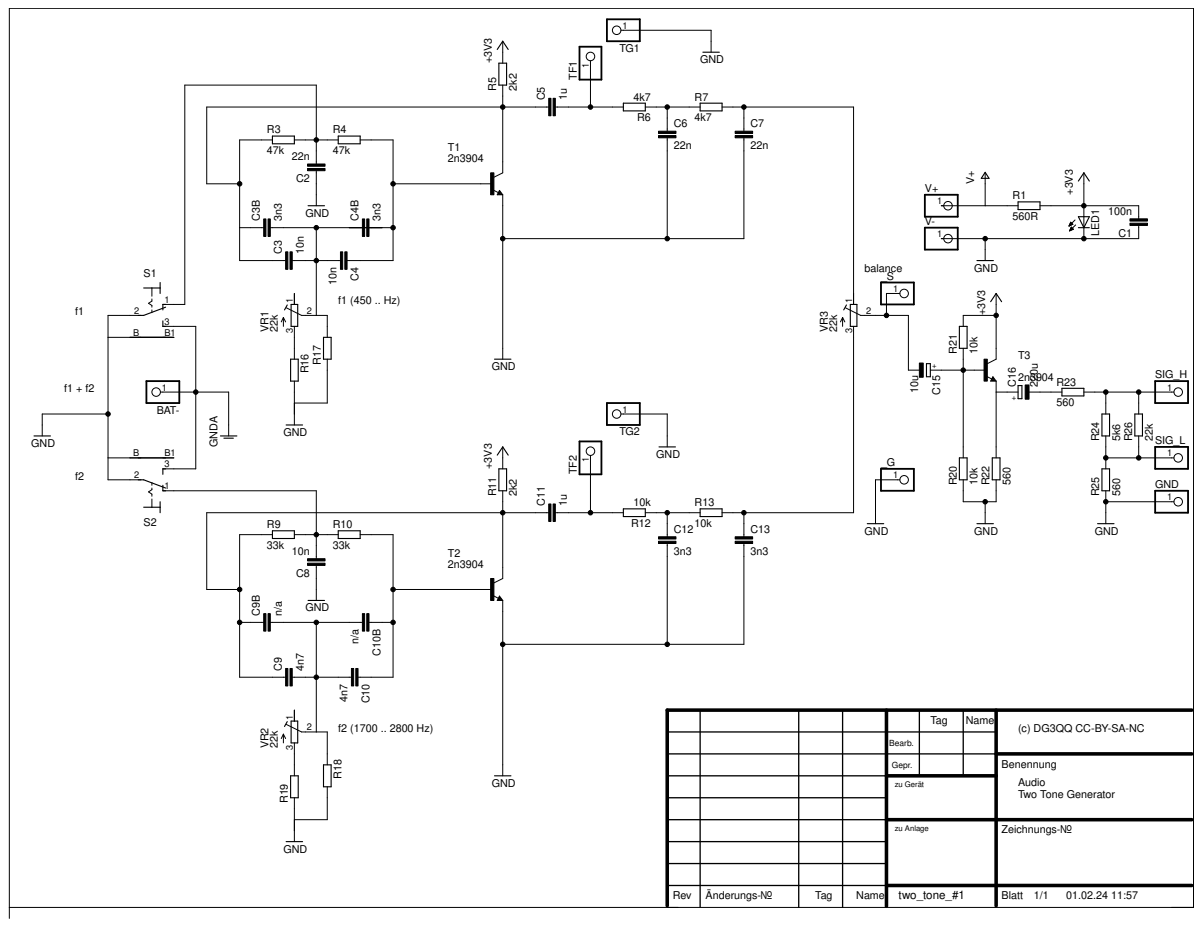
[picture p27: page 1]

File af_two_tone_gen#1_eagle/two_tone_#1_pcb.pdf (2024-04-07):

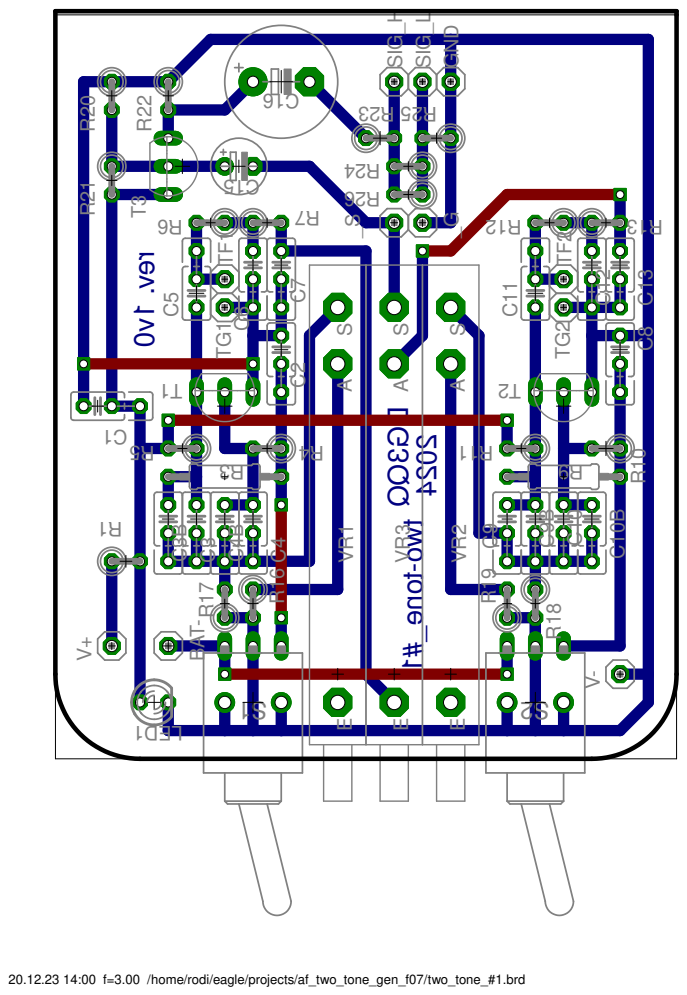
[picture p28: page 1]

20.12.23 14:00 f=3.00 /home/rodi/eagle/projects/af_two_tone_gen_f07/two_tone_#1.brd

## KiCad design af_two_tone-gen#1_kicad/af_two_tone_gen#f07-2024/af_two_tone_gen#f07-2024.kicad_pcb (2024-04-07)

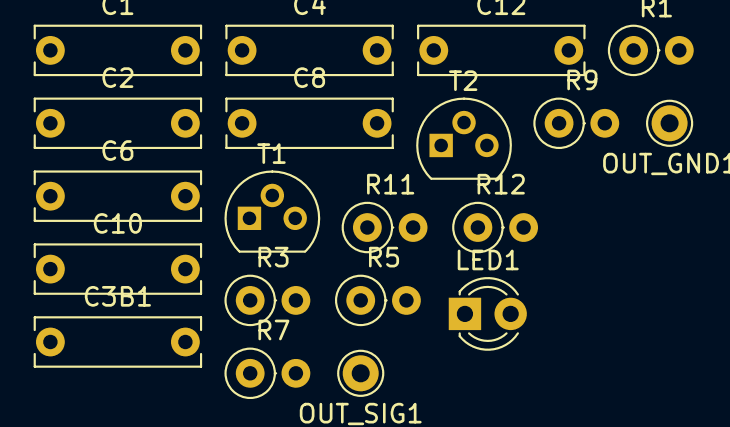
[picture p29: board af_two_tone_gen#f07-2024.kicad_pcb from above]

Board: 2 copper layers, 20 parts (0 on the bottom side), 8 nets, no tracks yet.

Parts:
C1: C-EU025_050-025X075; C_Rect_L9.0mm_W2.5mm_P7.50mm_MKT
C2, C6: 22n; C_Rect_L9.0mm_W2.5mm_P7.50mm_MKT
C3B1, C12: 3n3; C_Rect_L9.0mm_W2.5mm_P7.50mm_MKT
C4, C8: 10n; C_Rect_L9.0mm_W2.5mm_P7.50mm_MKT
C10: 4n7; C_Rect_L9.0mm_W2.5mm_P7.50mm_MKT
LED1: LED3MM; LED_D3.0mm
OUT_GND1: PINHD-1X1; Pin_D1.0mm_L10.0mm
OUT_SIG1: PINHD-1X1; Pin_D1.0mm_L10.0mm
R1: R-EU_0207_2V; R_Axial_DIN0207_L6.3mm_D2.5mm_P2.54mm_Vertical
R3: 47k; R_Axial_DIN0207_L6.3mm_D2.5mm_P2.54mm_Vertical
R5, R11: 2k2; R_Axial_DIN0207_L6.3mm_D2.5mm_P2.54mm_Vertical
R7: 4k7; R_Axial_DIN0207_L6.3mm_D2.5mm_P2.54mm_Vertical
R9: 33k; R_Axial_DIN0207_L6.3mm_D2.5mm_P2.54mm_Vertical
R12: 10k; R_Axial_DIN0207_L6.3mm_D2.5mm_P2.54mm_Vertical
T1, T2: 2n3904; TO-92

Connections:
+3V3: C1.2, R1.2, R5.2, R11.2
GND: C1.1, C2.1, C6.2, C8.1, C12.2, OUT_GND1.1
unnamed: C2.2, R3.2
unnamed: C3B1.1, R3.1, R5.1
unnamed: C6.1, R7.1
unnamed: C8.2, R9.2
unnamed: R9.1, R11.1
unnamed: C12.1, R12.2

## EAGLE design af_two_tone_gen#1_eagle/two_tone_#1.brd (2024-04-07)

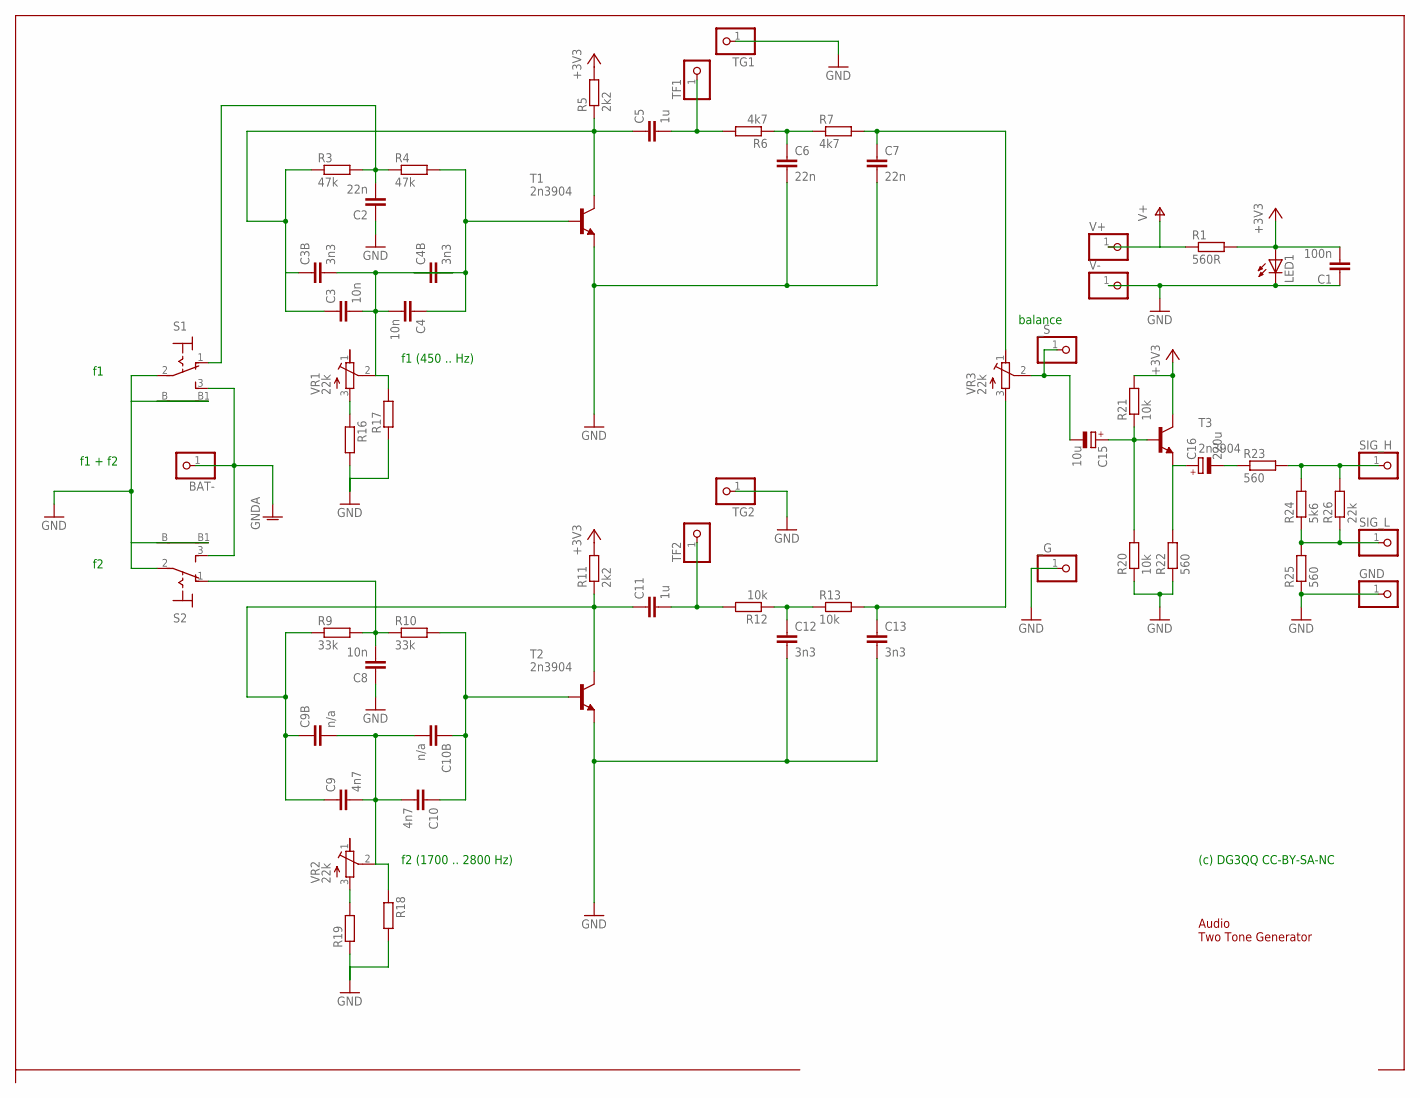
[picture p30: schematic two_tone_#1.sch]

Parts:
BAT-: PINHD-1X1; 1X01
C1: 100n; C025_050-025X075
C2, C6, C7: 22n; C025_050-025X075
C3, C4, C8: 10n; C025_050-025X075
C3B, C4B, C12, C13: 3n3; C025_050-025X075
C5, C11: 1u; C025_050-025X075
C9, C10: 4n7; C025_050-025X075
C9B, C10B: n/a; C025_050-025X075
C15: 10u; E2,5-5
C16: 220u; E5-10,5
GND: PINHD-1X1; 1X01
LED1: LED3MM
R1: 560R; 0207/2V
R3: 47k; 0207/10
R4: 47k; 0207/2V
R5, R11: 2k2; 0207/2V
R6, R7: 4k7; 0207/2V
R9: 33k; 0207/10
R10: 33k; 0207/2V
R12, R13, R20, R21: 10k; 0207/2V
R16, R17, R18, R19: R-EU_0207/2V; 0207/2V
R22, R23, R25: 560; 0207/2V
R24: 5k6; 0207/2V
R26: 22k; 0207/2V
S1, S2: 9070-1W
SIG_H: PINHD-1X1; 1X01
SIG_L: PINHD-1X1; 1X01
T1, T2, T3: 2n3904; TO92-EBC
TF1, TF2: PINHD-1X1; 1X01
TG1, TG2: PINHD-1X1; 1X01
V+: PINHD-1X1; 1X01
V-: PINHD-1X1; 1X01
VR1, VR2, VR3: 22k; SPINDLE_414S6
_G: PINHD-1X1; 1X01
_S: PINHD-1X1; 1X01

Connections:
+3V3: C1.2, LED1.A, R1.2, R5.2, R11.2, R21.2, T3.C
BAT-: BAT-.1, S1.3 (S), S2.3 (S)
GND: C1.1, C2.1, C6.2, C7.2, C8.1, C12.2, C13.2, GND.1, LED1.K (C), R16.2, R17.1, R18.2, R19.1, R20.1, R22.1, R25.1, S1.2, S1.B, S1.B1, S2.2, S2.B, S2.B1, T1.E, T2.E, TG1.1, TG2.1, V-.1, _G.1
unnamed: C5.2, R6.2, TF1.1
unnamed: C6.1, R6.1, R7.1
unnamed: C2.2, R3.2, R4.1, S1.1 (O)
unnamed: C4.1, C4B.1, R4.2, T1.B
unnamed: C3.1, C3B.1, C5.1, R3.1, R5.1, T1.C
unnamed: C3.2, C3B.2, C4.2, C4B.2, R17.2, VR1.2 (S)
unnamed: C7.1, R7.2, VR3.1 (A)
unnamed: C8.2, R9.2, R10.1, S2.1 (O)
unnamed: C10.1, C10B.1, R10.2, T2.B
unnamed: C9.1, C9B.1, C11.1, R9.1, R11.1, T2.C
unnamed: C9.2, C9B.2, C10.2, C10B.2, R18.1, VR2.2 (S)
unnamed: C11.2, R12.2, TF2.1
unnamed: C12.1, R12.1, R13.1
unnamed: C13.1, R13.2, VR3.3 (E)
unnamed: R19.2, VR2.3 (E)
unnamed: C15.+, R20.2, R21.1, T3.B
unnamed: C15.-, VR3.2 (S), _S.1
unnamed: R16.1, VR1.3 (E)
unnamed: C16.+, R22.2, T3.E
unnamed: C16.-, R23.1
unnamed: R23.2, R24.2, R26.2, SIG_H.1
unnamed: R24.1, R25.2, R26.1, SIG_L.1
V+: R1.1, V+.1

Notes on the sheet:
balance
f1 (450 .. Hz)
f2 (1700 .. 2800 Hz)
f1 + f2
(c) DG3QQ CC-BY-SA-NC
Audio Two Tone Generator

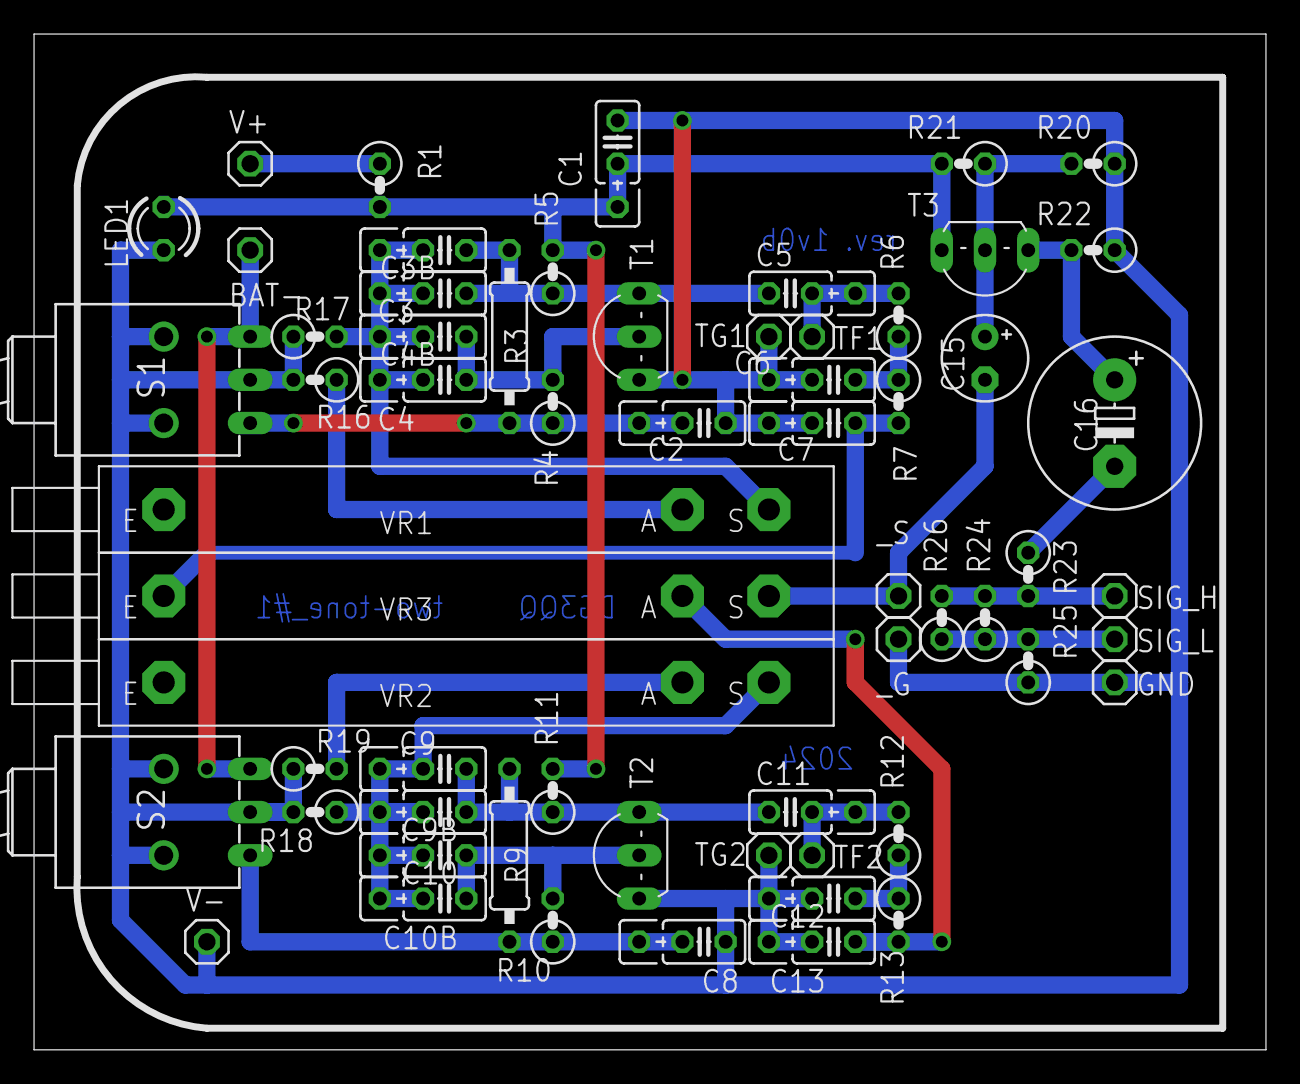
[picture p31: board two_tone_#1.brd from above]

Board: 2 copper layers, 72.4 x 59.7 mm, 62 parts (0 on the bottom side), 26 nets.

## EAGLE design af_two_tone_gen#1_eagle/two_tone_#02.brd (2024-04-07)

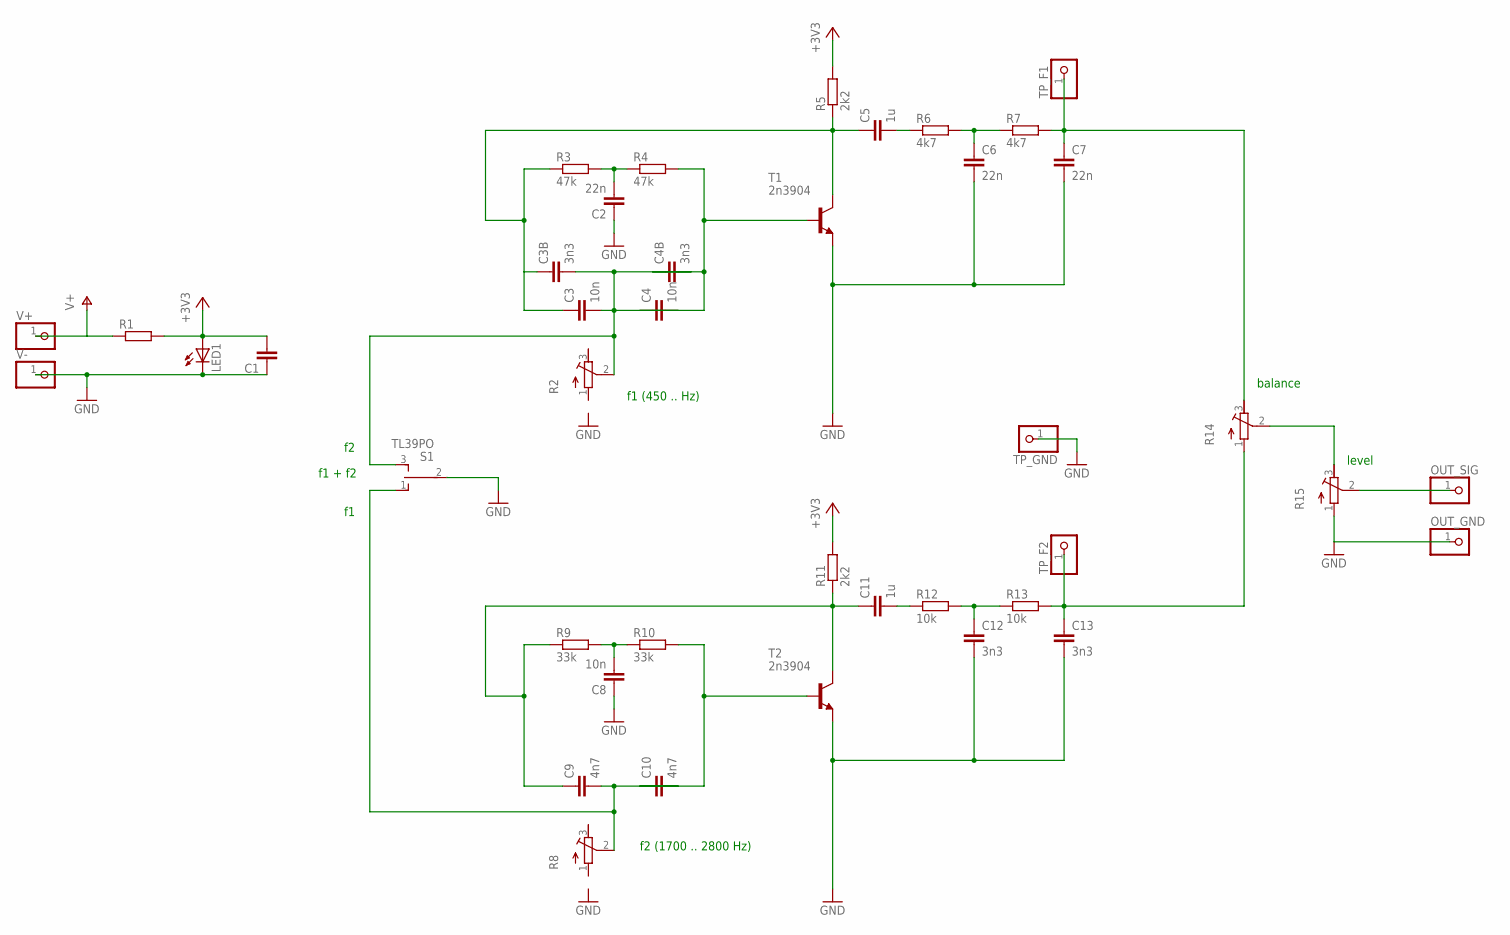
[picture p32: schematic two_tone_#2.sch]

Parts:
C1: C-EU025_050-025X075; C025_050-025X075
C2, C6, C7: 22n; C025_050-025X075
C3, C4, C8: 10n; C025_050-025X075
C3B, C4B, C12, C13: 3n3; C025_050-025X075
C5, C11: 1u; C025_050-025X075
C9, C10: 4n7; C025_050-025X075
LED1: LED3MM
OUT_GND: PINHD-1X1; 1X01
OUT_SIG: PINHD-1X1; 1X01
R1: R-EU_0207/2V; 0207/2V
R2, R8, R14, R15: R-TRIMM64W; RTRIM64W
R3: 47k; 0207/10
R4: 47k; 0207/5V
R5, R11: 2k2; 0207/10
R6: 4k7; 0207/10
R7: 4k7; 0207/2V
R9: 33k; 0207/10
R10: 33k; 0207/5V
R12: 10k; 0207/10
R13: 10k; 0207/2V
S1: TL39PO; TL3XPO
T1, T2: 2n3904; TO92-EBC
TP_F1, TP_F2: PINHD-1X1; 1X01
TP_GND: PINHD-1X1; 1X01
V+: PINHD-1X1; 1X01
V-: PINHD-1X1; 1X01

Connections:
+3V3: C1.2, LED1.A, R1.2, R5.2, R11.2
GND: C1.1, C2.1, C6.2, C7.2, C8.1, C12.2, C13.2, LED1.K (C), OUT_GND.1, R15.1 (E), S1.2, T1.E, T2.E, TP_GND.1, V-.1
unnamed: C5.2, R6.1
unnamed: C6.1, R6.2, R7.1
unnamed: C2.2, R3.2, R4.1
unnamed: C4.1, C4B.1, R4.2, T1.B
unnamed: C3.1, C3B.1, C5.1, R3.1, R5.1, T1.C
unnamed: C3.2, C3B.2, C4.2, C4B.2, R2.2 (S), S1.3 (S)
unnamed: C7.1, R7.2, R14.3 (A), TP_F1.1
unnamed: C8.2, R9.2, R10.1
unnamed: C10.1, R10.2, T2.B
unnamed: C9.1, C11.1, R9.1, R11.1, T2.C
unnamed: C9.2, C10.2, R8.2 (S), S1.1 (O)
unnamed: C11.2, R12.1
unnamed: C12.1, R12.2, R13.1
unnamed: C13.1, R13.2, R14.1 (E), TP_F2.1
unnamed: R14.2 (S), R15.3 (A)
unnamed: OUT_SIG.1, R15.2 (S)
V+: R1.1, V+.1

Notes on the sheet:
balance
level
f1 (450 .. Hz)
f2 (1700 .. 2800 Hz)
f1 + f2

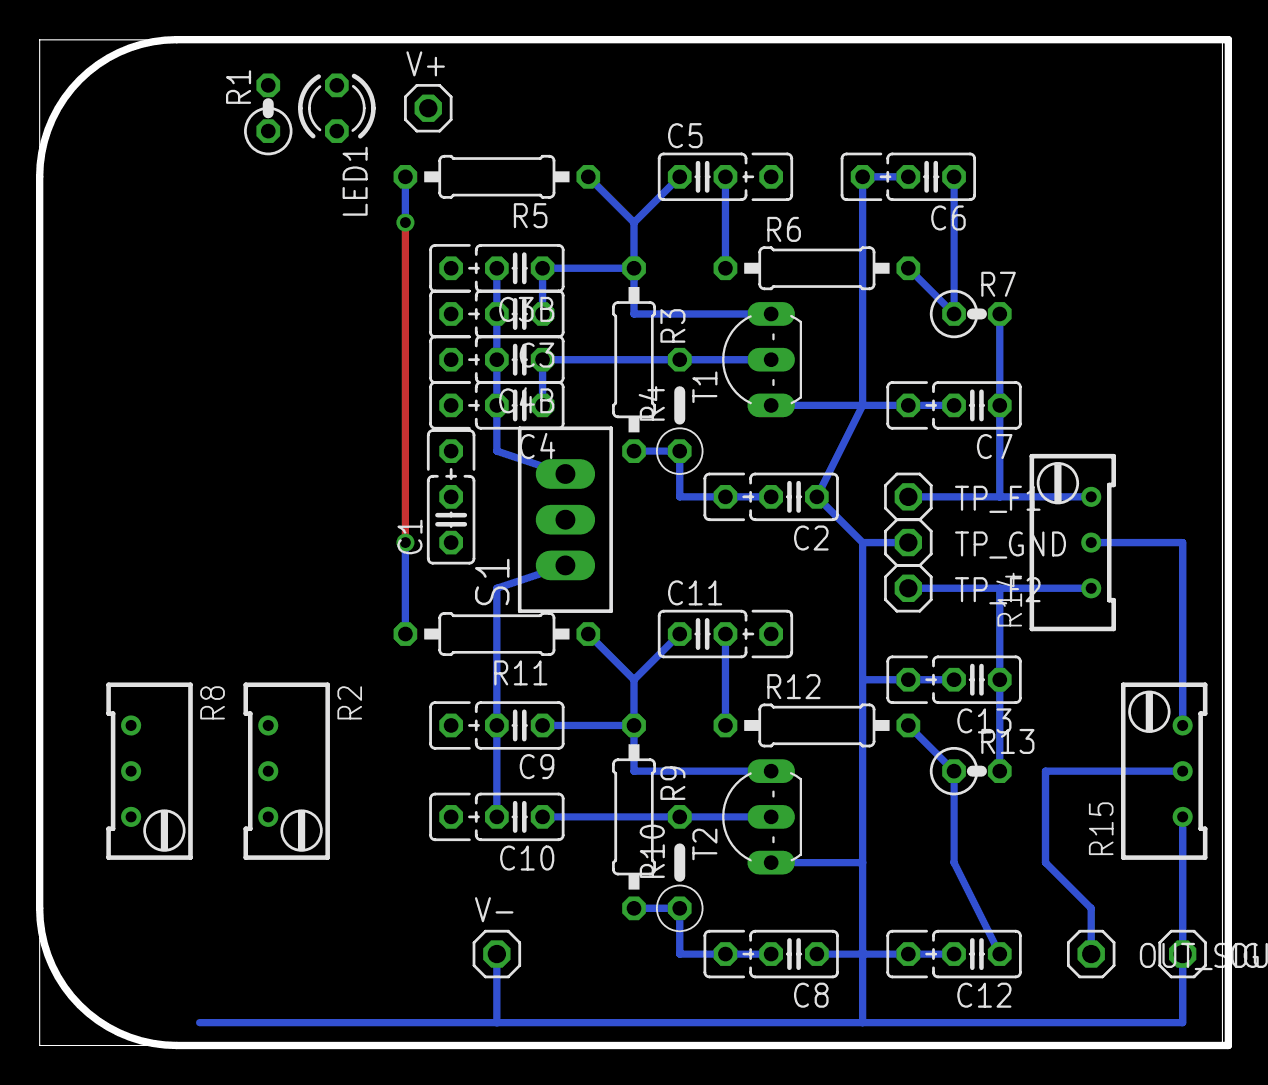
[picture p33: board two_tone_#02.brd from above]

Board: 2 copper layers, 66.0 x 55.9 mm, 41 parts (0 on the bottom side), 19 nets.
